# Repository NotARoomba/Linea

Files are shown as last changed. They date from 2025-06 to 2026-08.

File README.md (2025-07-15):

<h1 align="center">
  <br>
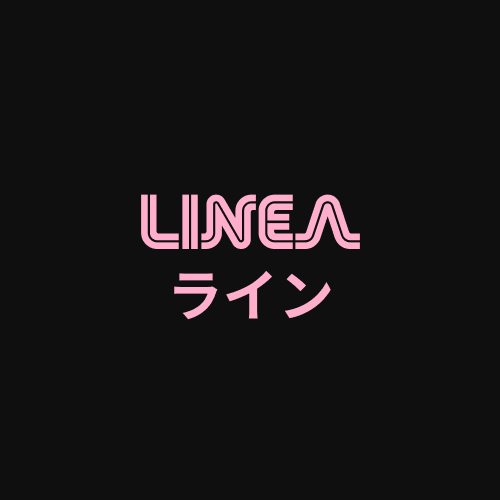
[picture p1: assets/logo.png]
Linea
  
  <br>
  Linea
  <br>
</h1>

<h4 align="center">
Project files for a custom EMR tablet from scratch.

Inspired by [Project Patchouli](https://gitlab.com/yukidama/patchouli).

</h4>

<div align="center">





</div>

<p align="center">
  <a href="#key-features">Key Features</a> •
  <a href="#case-and-cad">Case & CAD</a> •
  <a href="#pcb">PCB</a> •
  <a href="#bom">BOM</a> •
  <a href="#credits">Credits</a> •
  <a href="#license">License</a>
</p>

<!---
![schematic](https://raw.githubusercontent.com/NotARoomba/Linea/main/assets/schematic.png)
![pcb](https://raw.githubusercontent.com/NotARoomba/Linea/main/assets/pcb.png)
![build](https://raw.githubusercontent.com/NotARoomba/Linea/main/assets/windowed.png)
--->

## Key Features

- ~500kHz scanning rate
- Large (170x110mm) drawing area
- Bluetooth support (via STM32)
- USB-C for data and charging
- ~~Pen~~ (for another version)

## Case and CAD

The case includes:

- 3D printed parts: a base and a top cover
- Snap-fit case

Designed in Fusion 360.

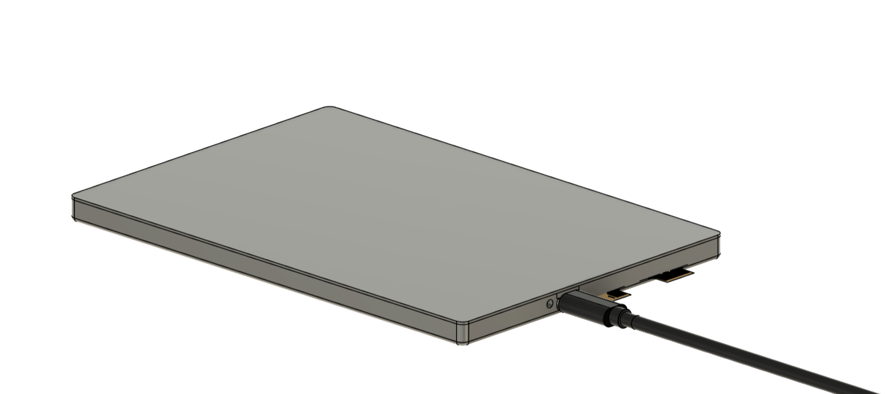
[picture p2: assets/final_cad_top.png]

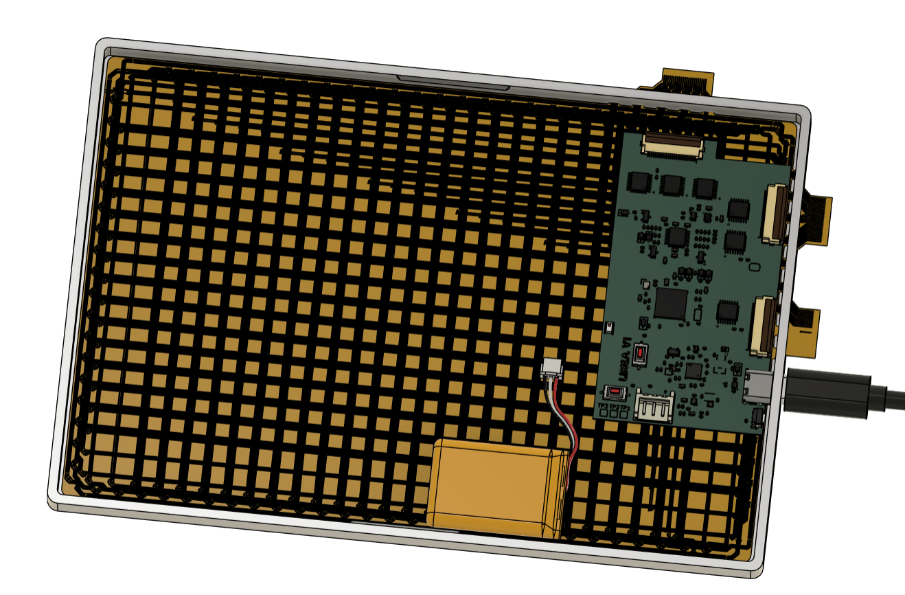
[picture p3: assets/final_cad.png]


## PCB

Designed in KiCad. Notable points:

- STM32WB55RGV6TR for bluetooth support
- LiPo battery charging circuit
- USB-C
- 2 ground planes
- FPC touchpad

The PCB has 2 components, the FPC coil grid and the main board.

### FPC

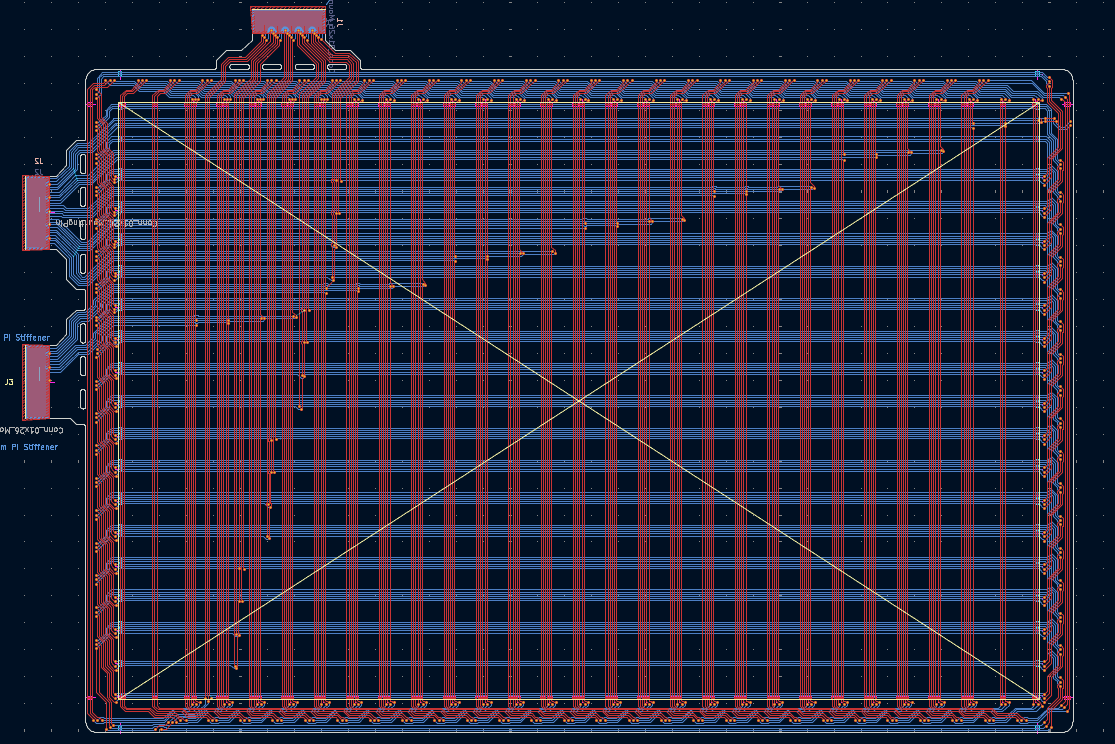
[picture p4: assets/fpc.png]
FPC board


### Main Board

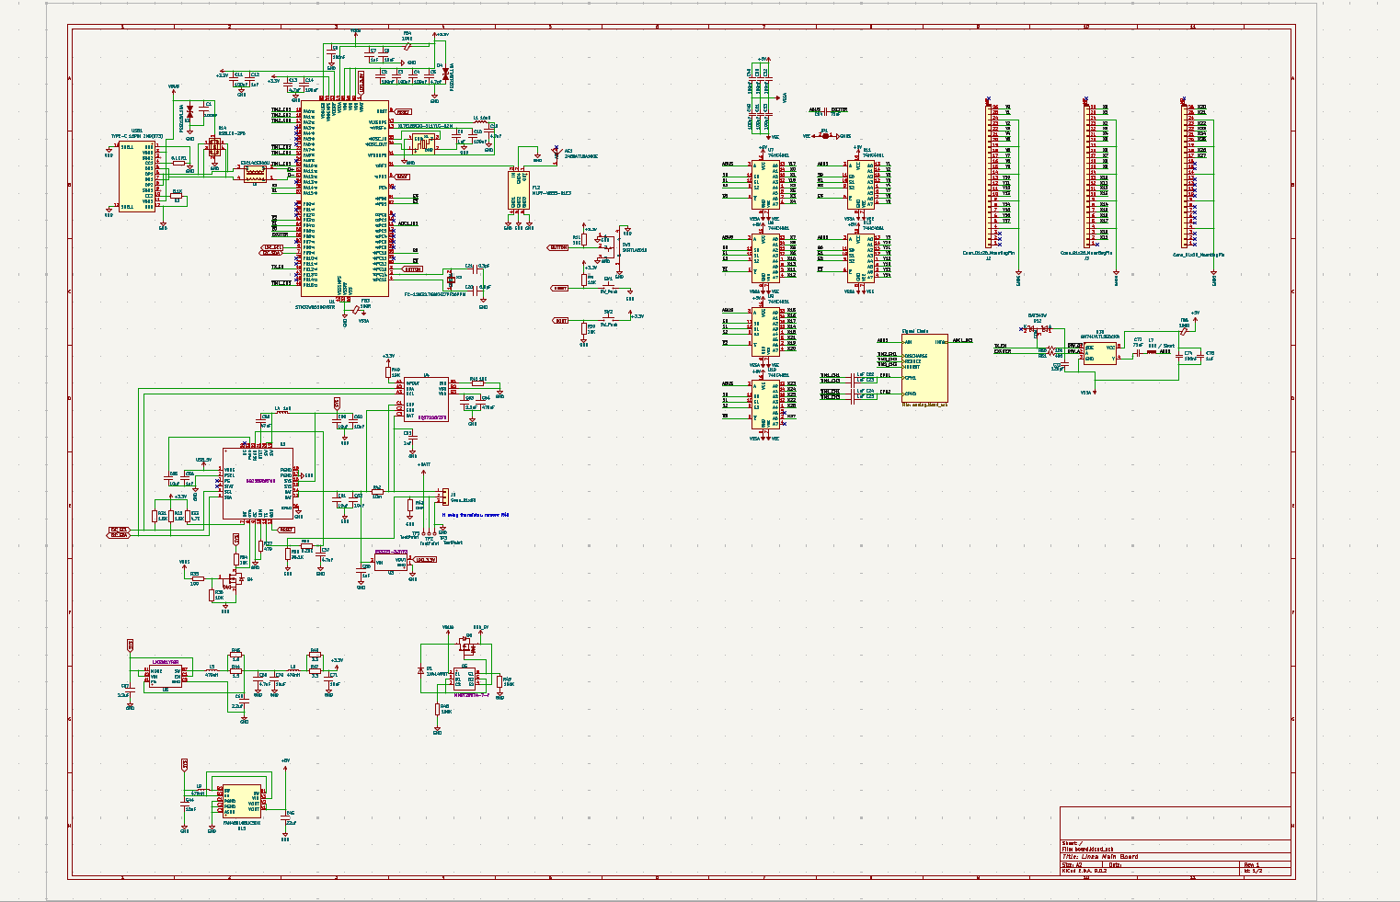
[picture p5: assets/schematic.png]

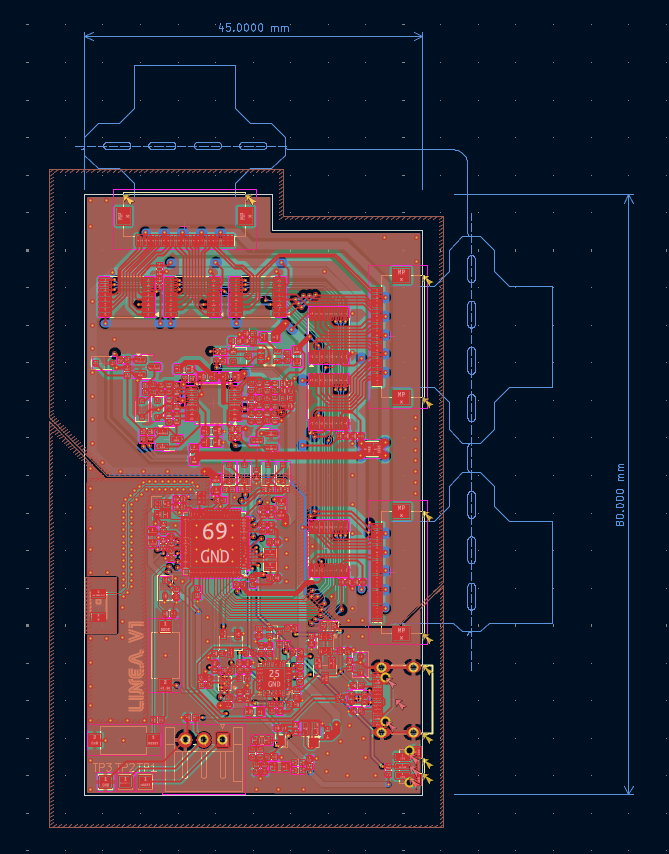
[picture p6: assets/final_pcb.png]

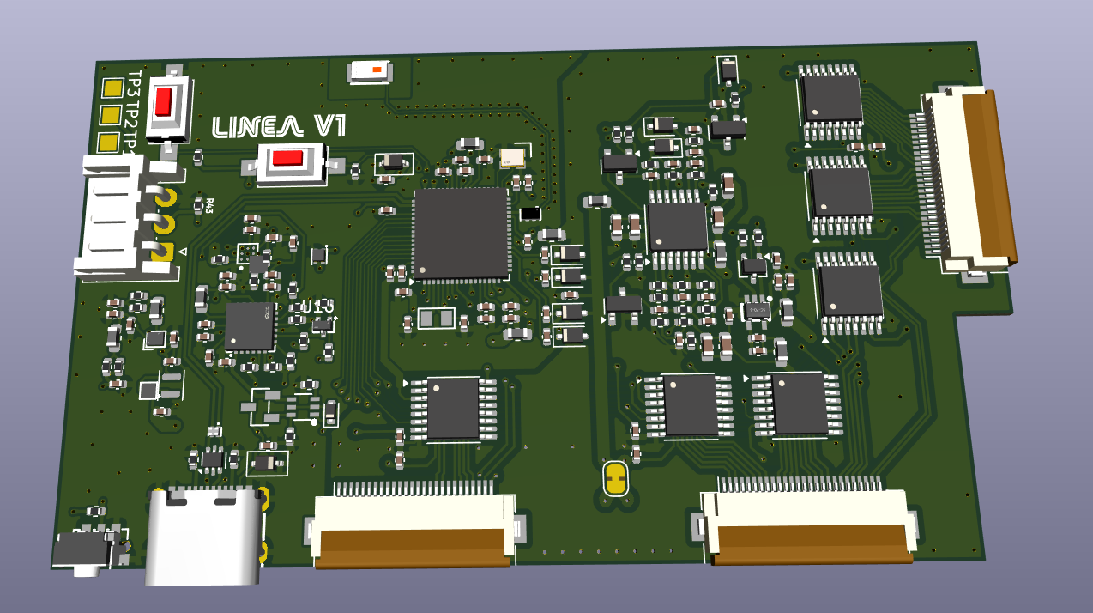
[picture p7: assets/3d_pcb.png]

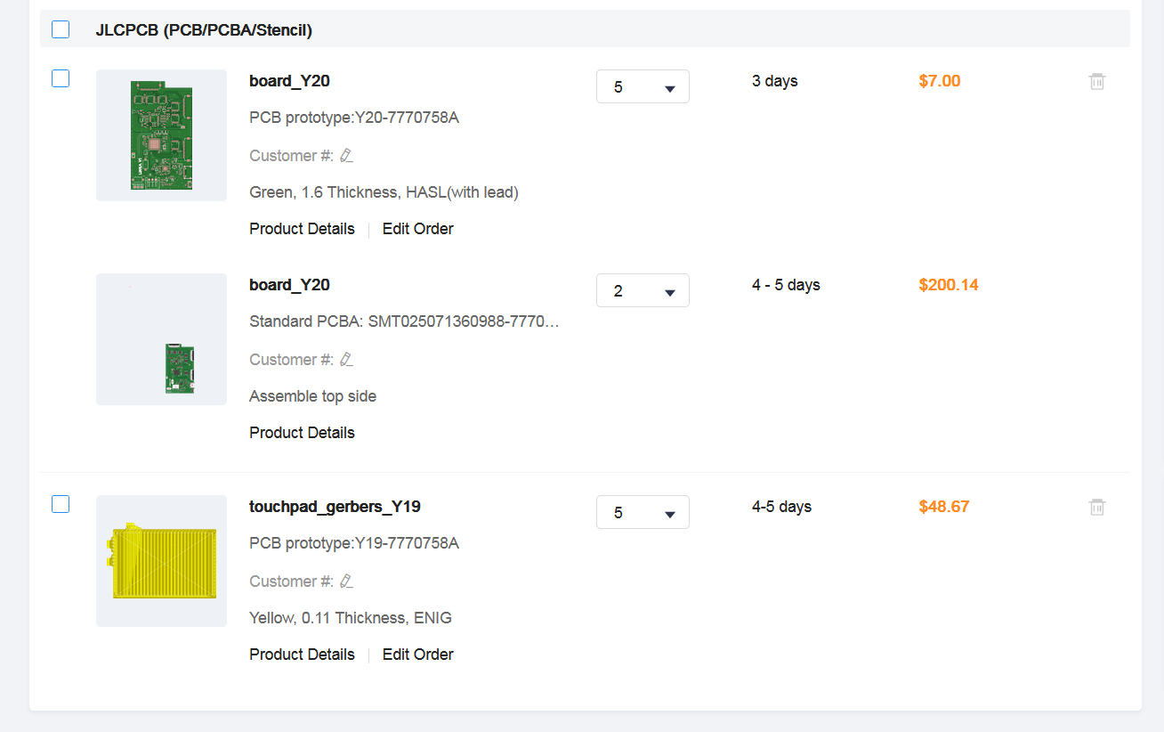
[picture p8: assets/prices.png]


## BOM

| Item | Price (USD) | Source |
| --- | --- | --- |
| FPC Board | 48.67 | JLCPCB |
| Main Board | 207.14 | JLCPCB |
| Test Pen | 12.35 | [Aliexpress](https://www.aliexpress.com/item/1005001860233195.html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) |
| LiPo 1200mAh | 12.00 | [Online Marketplace](https://articulo.mercadolibre.com.co/MCO-897219547-bateria-37v-1200mah-litio-lipo-35-x-6cm-ancho-05cm-_JM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) |
| **Subtotal** | 280.16 | |
| **Shipping** | 30.00 | Estimated |
| **Total** | 310.16 | |

<!-- https://articulo.mercadolibre.com.co/MCO-568567056-lapiz-repuesto-tabla-digitalizadora-xp-pen-p03-no-wacom-_JM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 -->

## Credits

- [Project Patchouli](https://gitlab.com/yukidama/patchouli)
- [Flipper Zero](https://docs.flipper.net/development/hardware)
- Check `/references` for more information

This project uses:

- [KiCad](https://www.kicad.org/)
- [STM32MX](https://www.st.com/en/development-tools/stm32cubemx.html)
- [Fusion 360](https://www.autodesk.com/products/fusion-360/overview)

## You may also like...

- [Niveles De Niveles](https://github.com/NotARoomba/NivelesDeNiveles) – Real-time flood alert app
- [ROCKETMEN](https://github.com/NotARoomba/ROCKETMEN) – Custom flight controller files
- [Tamaki](https://github.com/NotARoomba/Tamaki) – A cute HackPad

## License

MIT

---

> [notaroomba.dev](https://notaroomba.dev) &nbsp;&middot;&nbsp;
> GitHub [@NotARoomba](https://github.com/NotARoomba)

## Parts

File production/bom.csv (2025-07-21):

Designator | Footprint | Quantity | Value | LCSC Part #
AE1 | ANT-SMD_L3.2-W1.6 | 1 | 2450AT18A100E | C89334
C1, C10, C11, C14, C2, C3, C4, C48, C49, C50, C51, C52, C53, C6, C74 | 0402 | 15 | 100nF
C12, C22, C23, C24, C25, C56, C65, C66, C7, C75, C9 | 0402 | 11 | 1uF
C13, C15, C57, C69 | 0402 | 4 | 4.7uF
C16, C19 | 0402 | 2 | 3.9nF
C17, C27 | 0603 | 2 | 3.6nF
C18, C73 | 0402 | 2 | 68nF
C20 | 0402 | 1 | 0.8pF
C21 | 0402 | 1 | 0.3pF
C26 | 0402 | 1 | 1nF
C28, C43 | 0402 | 2 | 470pF
C29, C30, C32, C33, C35, C36, C72 | 0402 | 7 | 120pF
C31, C44, C55, C59, C60, C61, C62, C70, C71 | 0402 | 9 | 10uF
C34 | 0402 | 1 | 560pF
C37, C38 | 0603 | 2 | 1uF
C39 | 0402 | 1 | 33pF
C40, C41 | 0603 | 2 | 100nF
C42 | 0402 | 1 | 220pF
C45 | 0402 | 1 | 22uF
C5 | 0402 | 1 | 4.7pF
C58 | 0402 | 1 | 47nF
C63, C67, C68 | 0402 | 3 | 2.2uF
C64 | 0402 | 1 | 470nF
C8 | 0402 | 1 | 10nF
D1 | D_SOD-523 | 1 | 1N4148WT
D10, D11, D5, D6, D7, D8, D9 | D_SOD-323F | 7 | BAT54J
D12 | SOT-323_SC-70 | 1 | BAT54SW
D3, D4 | D_SOD-323_TVS | 2 | PESD15VL1BA
FB1, FB2, FB3, FB4, FB5 | 0603 | 5 | 100R
FL2 | FILTER-SMD_6P-L1.6-W1.0-P0.50-BL | 1 | MLPF-WB55-01E3 | C2651048
J2, J3, J4 | Hirose_FH12-26S-0.5SH_1x26-1MP_P0.50mm_Horizontal | 3 | Conn_01x26_MountingPin | C262277
J5 | JST_EH_S3B-EH_1x03_P2.50mm_Horizontal | 1 | Conn_01x03 | C263754
JP1 | SolderJumper-2_P1.3mm_Bridged_RoundedPad1.0x1.5mm | 1 | ~
L1 | 0603 | 1 | 10uH
L4 | 0603 | 1 | 1uH
L5, L6 | 0603 | 2 | 470nH
L7 | 0603 | 1 | 60R / Short | C85834
L8 | FILTER-SMD_4P-L0.9-W0.7-P0.50-BL | 1 | EXC14CE900U | C178761
L9 | L_Murata_DFE201610P | 1 | 470nH | C882980
Q1, Q2, Q3 | SOT-23 | 3 | AO3400A
Q4 | SOT-523-3_L1.6-W0.8-P1.00-LS1.6-BR | 1 | ~ | C155524
Q5 | SOT-363_L2.0-W1.3-P0.65-LS2.1-BL | 1 | ~ | C460232
Q6 | SOT-23-3_L2.9-W1.3-P1.90-LS2.4-BR | 1 | ~ | C177033
R1, R2 | 0402 | 2 | 5.1K
R10, R11, R15, R21, R25, R29, R34, R36, R40, R41, R50, R9 | 0402 | 12 | 10K
R12, R14, R16, R23 | 0402 | 4 | 1K
R13, R51 | 0402 | 2 | 400
R17, R19, R22, R26 | 0402 | 4 | 12K
R18 | 0402 | 1 | 0
R20 | 0402 | 1 | 560
R24 | 0402 | 1 | 200
R27, R30, R35 | 0402 | 3 | 100
R28 | 0402 | 1 | 15k
R31, R32 | 0402 | 2 | 1.5K
R33 | 0402 | 1 | 4.7K
R37 | 0402 | 1 | 470
R38 | 0402 | 1 | 30.1K
R39 | 0402 | 1 | 5.23K
R42 | R2512 | 1 | WW25WR010FTL | C171418
R43 | 0402 | 1 | DNP
R44, R45 | 0402 | 2 | 1.5
R46, R47 | 0402 | 2 | 3.3
R48, R49 | 0402 | 2 | 100K
SW1, SW2 | SW_SPST_CK_RS282G05A3 | 2 | SW_Push | C318938
SW3 | KEY-SMD_SKRTLAE010 | 1 | SKRTLAE010 | C110293
TP1, TP2, TP3 | TestPoint_Pad_1.5x1.5mm | 3 | TestPoint
U1 | QFN-68-1EP_8x8mm_P0.4mm_EP6.4x6.4mm | 1 | STM32WB55RGV6
U10, U11, U12, U7, U8, U9 | TSSOP-16_4.4x5mm_P0.65mm | 6 | 74HC4051
U13 | SC-70-5_L2.1-W1.3-P0.65-LS2.1-TL | 1 | SN74LV1T125DCKR | C75925
U14 | SOT-666 | 1 | USBLC6-2P6
U15 | WLCSP-9_L1.2-W1.2-R3-C3-P0.40-BL | 1 | FAN48610BUC50X | C890711
U16 | UTDFN-4_L1.0-W1.0-P0.63-BL-EP-1 | 1 | RS3221-3.3YUTDN4 | C2924279
U2 | QFN-24_L4.0-W4.0-P0.50-TL-EP2.7 | 1 | ~ | C181475
U4 | DSBGA-9_L1.7-W1.6-R3-C3-P0.50-BL | 1 | ~ | C528617
U5 | DSBGA-6_L1.4-W1.1-R3-C2-P0.40-BL | 1 | ~ | C2070970
U6 | TSSOP-14_4.4x5mm_P0.65mm | 1 | COS8054TR
USB1 | USB-C-SMD_TYPE-C-6PIN-2MD-073 | 1 | TYPE-C 16PIN 2MD(073) | C2765186
X1 | CRYSTAL-SMD_4P-L2.0-W1.6-BL | 1 | XL7EL89CKI-111YLC-32M | C2965582
X2 | FC-12M_L2.0-W1.2 | 1 | FC-12M32.768KHZ7PF20PPM | C99009

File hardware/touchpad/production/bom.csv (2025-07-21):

Designator | Footprint | Quantity | Value | LCSC Part #
J1, J2, J3 | Hirose_FH12-26S-0.5SH(55)-FPC_1 | 3 | Conn_01x26_MountingPin
J10, J100, J101, J102, J103, J104, J105, J106, J107, J108, J109, J11, J110, J111, J112, J113, J114, J115, J116, J117, J118, J119, J12, J120, J121, J122, J123, J124, J125, J126, J127, J128, J129, J13, J130, J131, J132, J133, J134, J135, J136, J137, J138, J139, J14, J140, J141, J142, J143, J144, J145, J146, J147, J148, J149, J15, J150, J151, J152, J153, J154, J155, J156, J157, J158, J159, J16, J160, J161, J162, J163, J164, J165, J166, J167, J168, J169, J17, J170, J171, J172, J173, J174, J175, J176, J177, J178, J179, J18, J180, J181, J182, J183, J184, J185, J186, J187, J19, J20, J21, J22, J23, J24, J25, J26, J27, J28, J29, J30, J31, J32, J33, J34, J35, J36, J37, J38, J39, J4, J40, J41, J42, J43, J44, J45, J46, J47, J48, J49, J5, J50, J51, J52, J53, J54, J55, J56, J57, J58, J59, J6, J60, J61, J62, J63, J64, J65, J66, J67, J68, J69, J7, J70, J71, J72, J73, J74, J75, J76, J77, J78, J79, J8, J80, J81, J82, J83, J84, J85, J86, J87, J88, J89, J9, J90, J91, J92, J93, J94, J95, J96, J97, J98, J99 | coil_terminal_3p | 184 | Conn_02x03_Odd_Even

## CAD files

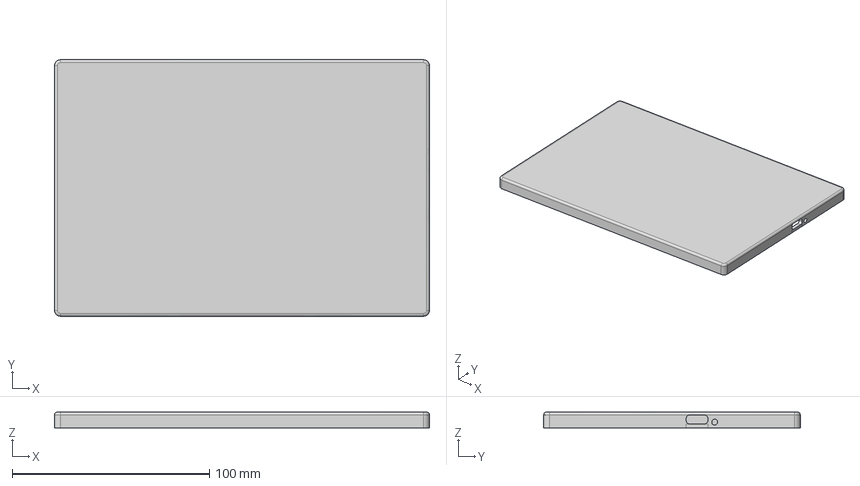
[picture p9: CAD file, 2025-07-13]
production/case_base.step
190.0 x 130.0 x 8.00 mm

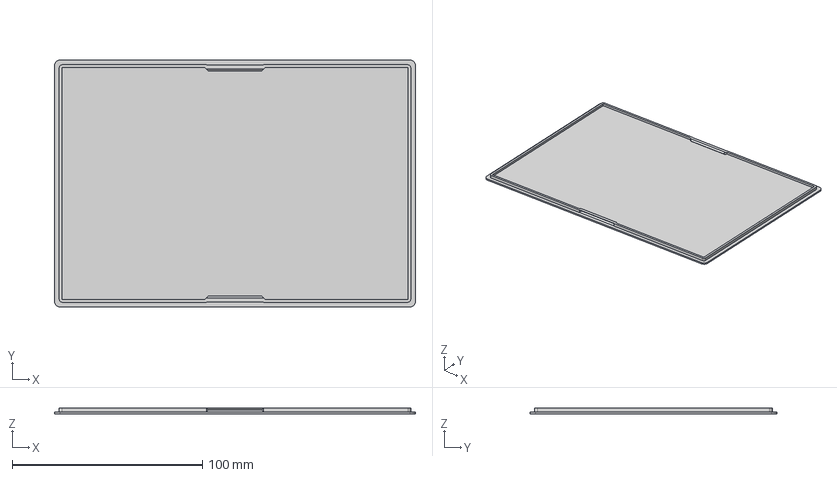
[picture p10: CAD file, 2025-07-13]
production/case_top.step
190.0 x 130.0 x 3.00 mm

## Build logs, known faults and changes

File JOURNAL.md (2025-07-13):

---
title: "Linea"
author: "Nathan Alspaugh (NotARoomba)"
description: "An EMR based drawing tablet (like a Wacom) from scratch!"
created_at: "2025-06-20"
time_spent: ~64 Hours
---

# July 20-22: Brainstorming and Research

I was initially inspired to start this project after the principal of my school promised me a Wacom One because of my academic excellence, but after some time I never recieved the tablet so I decided to make my own. I then looked up to see if I could find some inspiration and I found a [YouTube video](https://www.youtube.com/watch?v=igVscvWAR1s) (<10K views) of someone actually making and studying the pencils from common drawing tablets.

EMR tablets work based off of inductors (coils) being able to b affected by magnetic fields and being able to turn such fields into electricity (with some caveats). The tablet has a grid of coils ith AC current flowing through them, this alternation causes a magnetic field to form. THis magnetic field is especially useful because if another inductor coms close to the field, it can recive a bit of current and using a capacitor, it can be stored. This is the basic principle of how those pens manage to work without batteries.

I saw that he originally made on to convert a laptop into a drawing tablet so I kinda wanted to do the same but with some improvements:

- USB-C
- Bluetooth
- Custom software to configure pen sensitivity

As the original tablet neded a wired connection I decided that this would be a fun challenge to tackle.

After looking through the repository on GitLab and opeing up the schematics for the tablet (more specifically the coil grid) I was greeted with this:

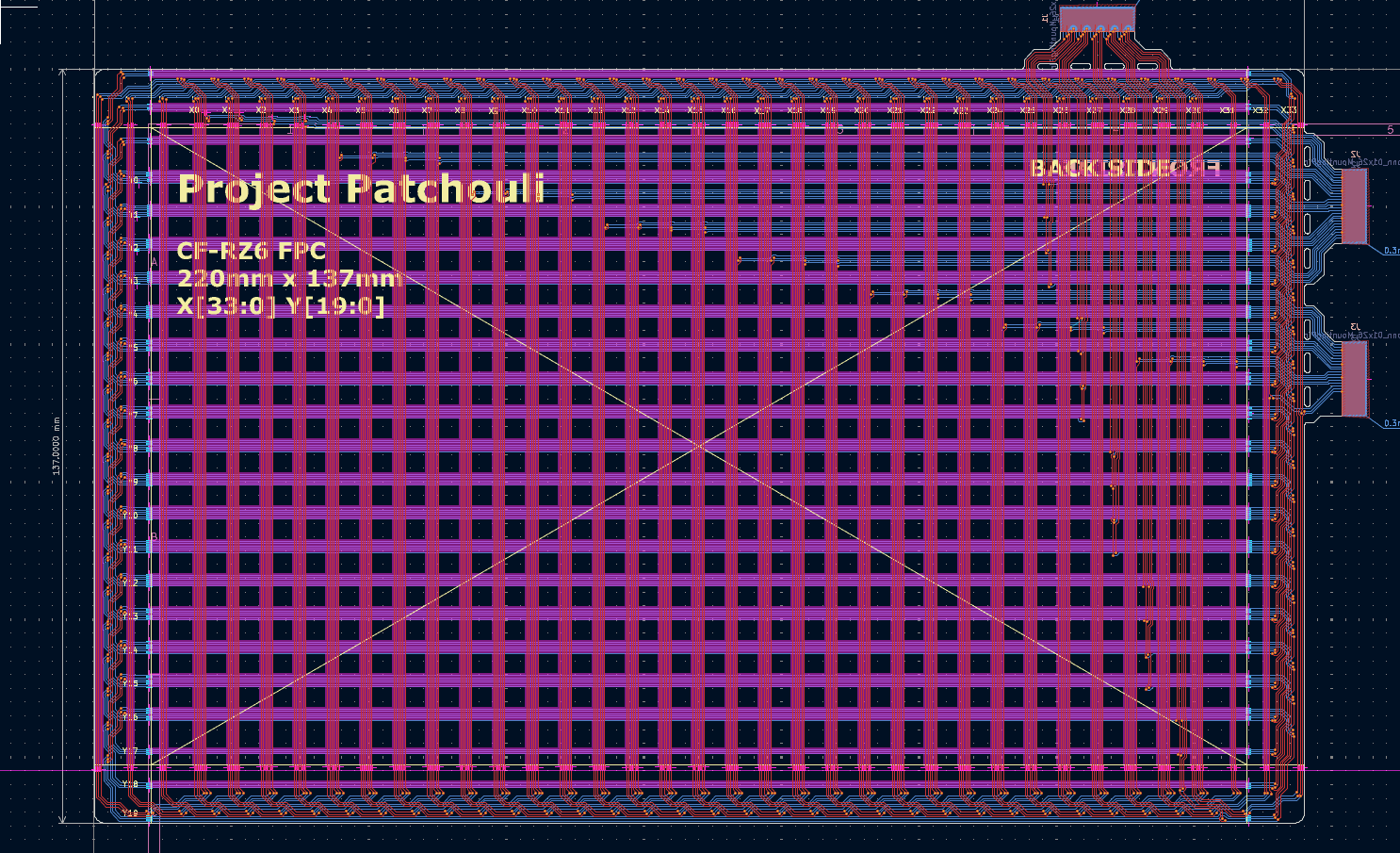
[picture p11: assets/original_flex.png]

(look at all those coils)

While I could copy it, I wanted a tablet under 200mm and also to be able to understand it. So I looked through some [patents](https://patents.google.com/patent/US4634973A) that were referenced in the YouTube video and found that that the coils could be made up of any number of turns, in this case 3 turns (better pen detection).

I plan on making 3 components, a flexible circuit that recives the signal from the pen, a central "motherboard" that processes the signal from the FPC, and finally a ~~pen that can interact with the tablet~~ (seperate project).

**Time Spent:** 2 Hours

# June 23: FPC Design

I started by using a script to make one side of the coils.

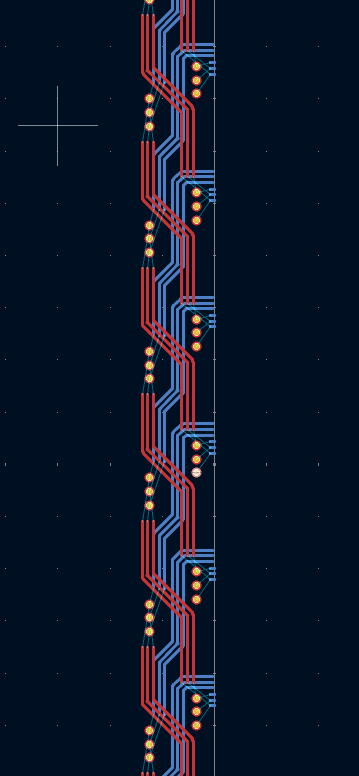
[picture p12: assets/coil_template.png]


I then had to connect them in a way so that they looped around like in the original schematic

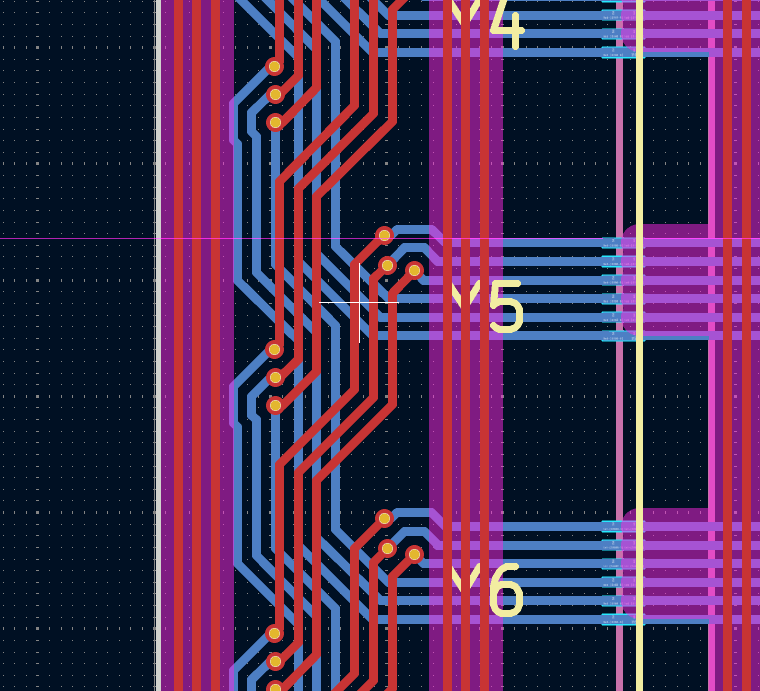
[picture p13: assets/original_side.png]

(orignal)

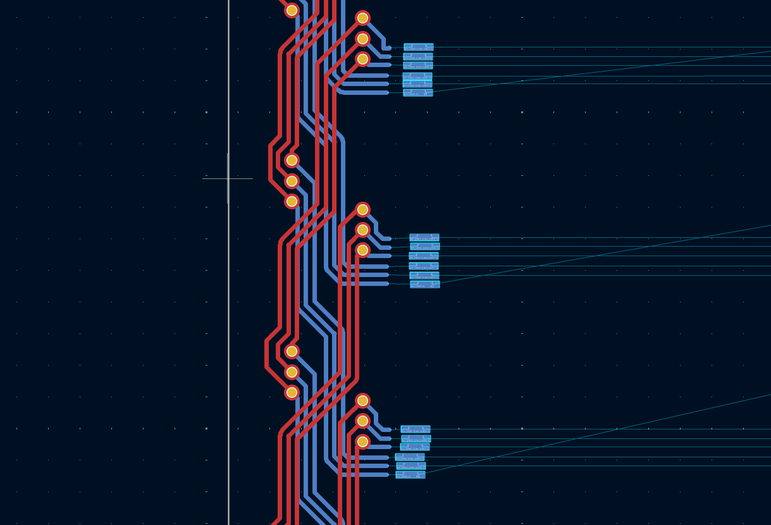
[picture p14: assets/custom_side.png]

(mine after complting the horizontal coils)

**Time Spent:** 5 Hours

# June 24: FPC continued...

After a while I got the Y-plane done

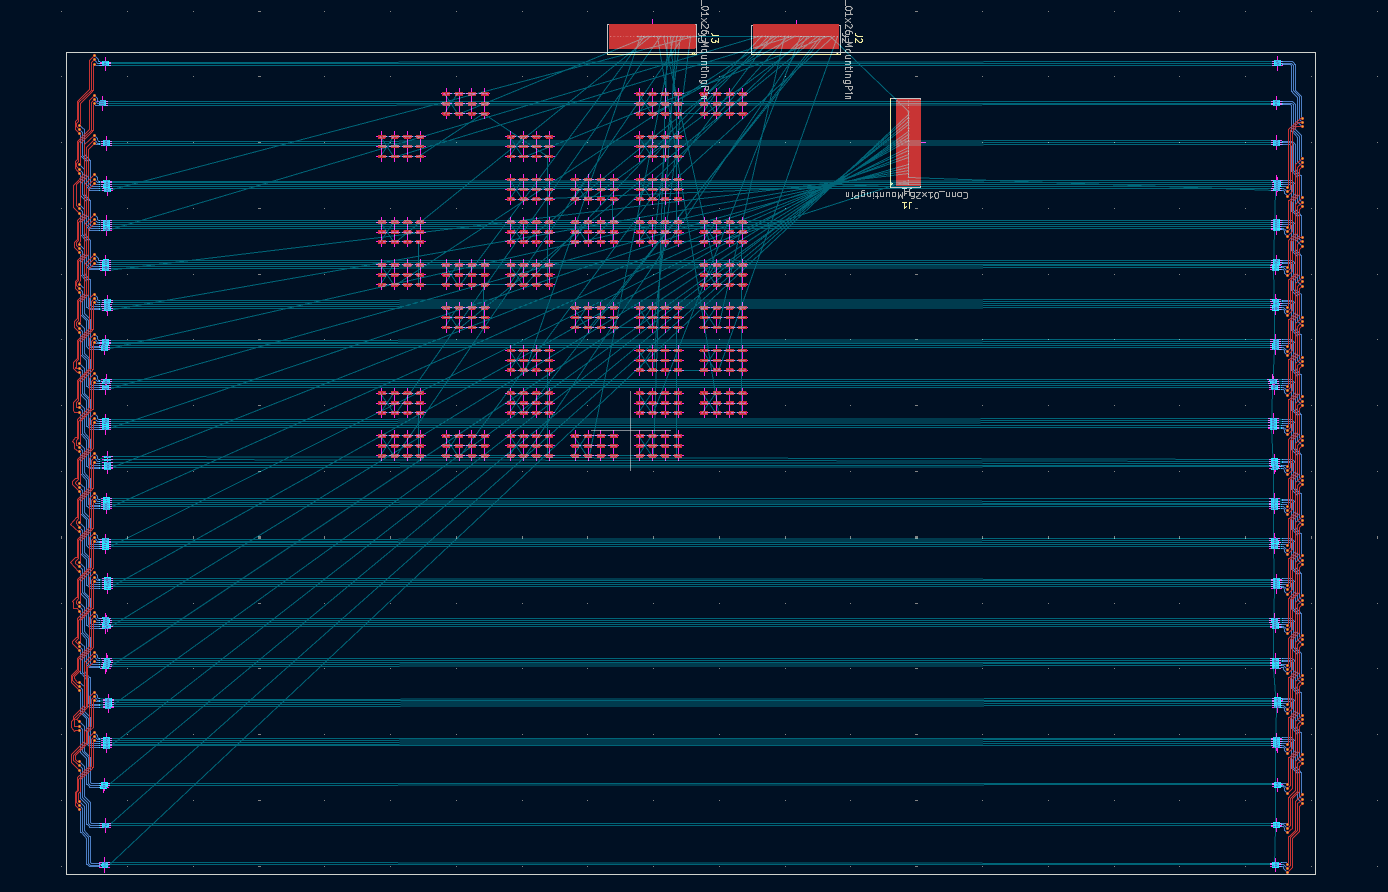
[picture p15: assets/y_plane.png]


but thats when I recieved a response from the original creator about a question I had about the coil design. Originally the coils looked like this, and I had a question as to why the middle loop wasn't connected to anything. Apparently that was a bug... after all that wiring...

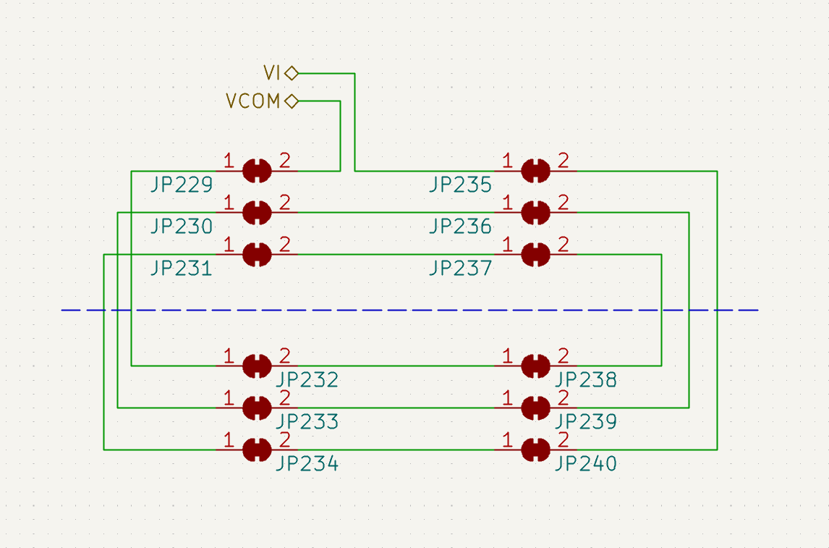
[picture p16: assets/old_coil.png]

(old coil)

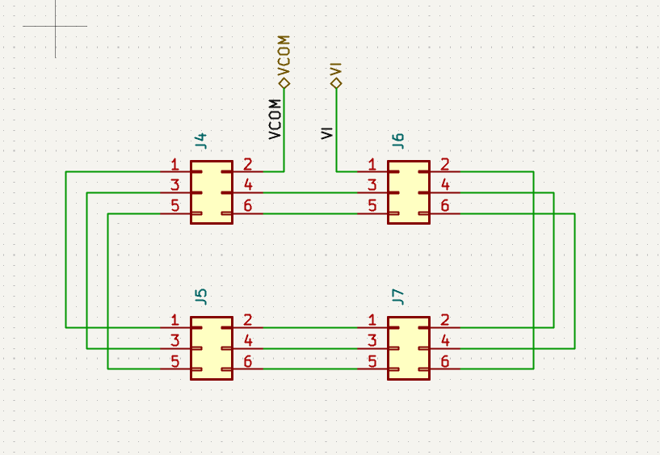
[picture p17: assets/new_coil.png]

(new coil)

I asked few more questions that helped clarify things like the trace width and how to efficently connect all the components and got to work on a new design. (by hand)

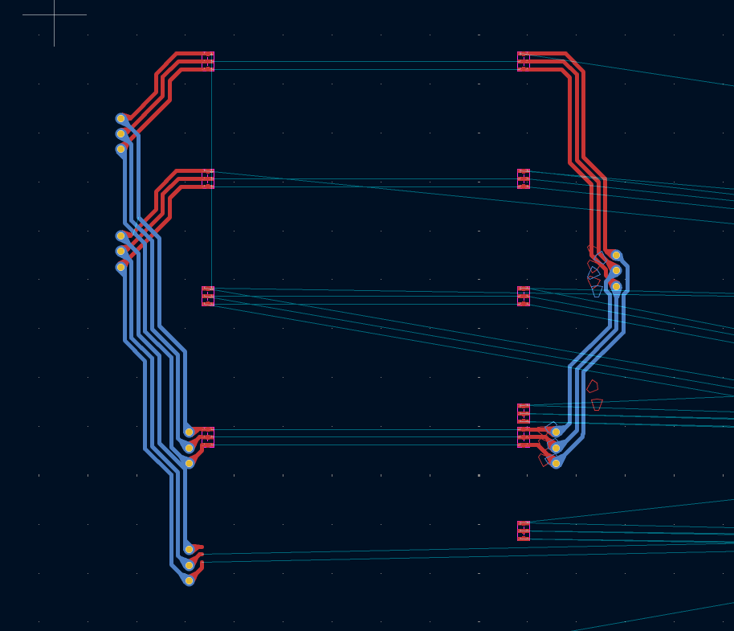
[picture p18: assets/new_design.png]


After a few hours of tweaking I finally got the right design.
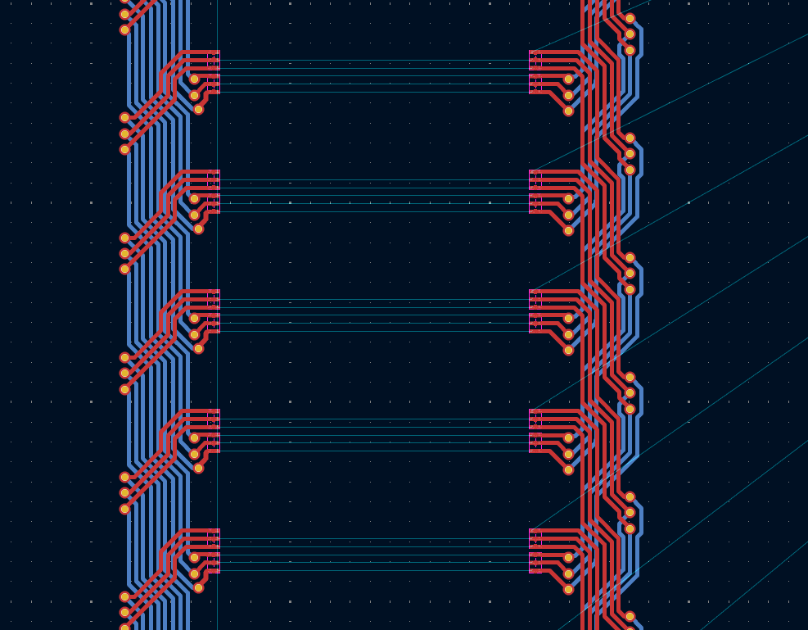
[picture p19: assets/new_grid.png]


**Time Spent:** 7 Hours

# June 25: Rewiring (again...)

After yesterday's fail I decided to take a break and then start the wiring again, I didn't make much progress today but I got both axis done.

**Time Spent:** 1 Hour

# June 29: Finished FPC

FInally after working all day (took a few days off), I finally completed the FPC.



The supposed active area is 170x110mm which I think is pretty good.

Now I'm going to start research on the main board that connects to the FPC. I want it to have bluetooth and a good battery life so I chose the STM32WB55. I'll be using the Flipper Zero's schematics to wire it up as it uses the same chip.

**Time Spent:** 8 Hours

# June 30: Main Board Schematic

After researching and compiling schematics, I started work on creating the schematic for the board that will handle the connection from the touchpad and also bluetooth. I took inspiration from the connections for power and battery from the Flipper Zero docs and also the analog circuits from [Patchouli's repository](https://gitlab.com/yukidama/patchouli).



**Time Spent:** 6 Hours

# July 1: Main Board PCB

After finishing the schematic, I decided to take a break and plan what I had to do next in order of importance.

- Double triple check schematic
- Create main board PCB
- Fix FPC board to have 0.2mm trace spacing
- Create case in Fusion360
- (Optionally create pencil)

# July 3: Fix FPC Board

My OCD wouldn't let me move on until I'd fixed spacing on the board so I redid the coils and added everything again.

**Time Spent:** 4 Hours

# July 5-10: Main Board PCB (finally)

I started work on making the PCB and after watching a few tutorials on analog signals and pcb design (thanks Phil's Lab) I felt confident in starting to design the PCB.

I started by grouping all the components together based on the schematic and also taking refrence from the other designs in Patchouli (dont have many pictures as I was locked in). I then started wiring again taking inspiration from the schmatics using wider traces for power and ground and thn smaller traces for the data lines and analog crcuits. I also split the schematic into 2 ground planes. One for analog ground and another for the digital ground.

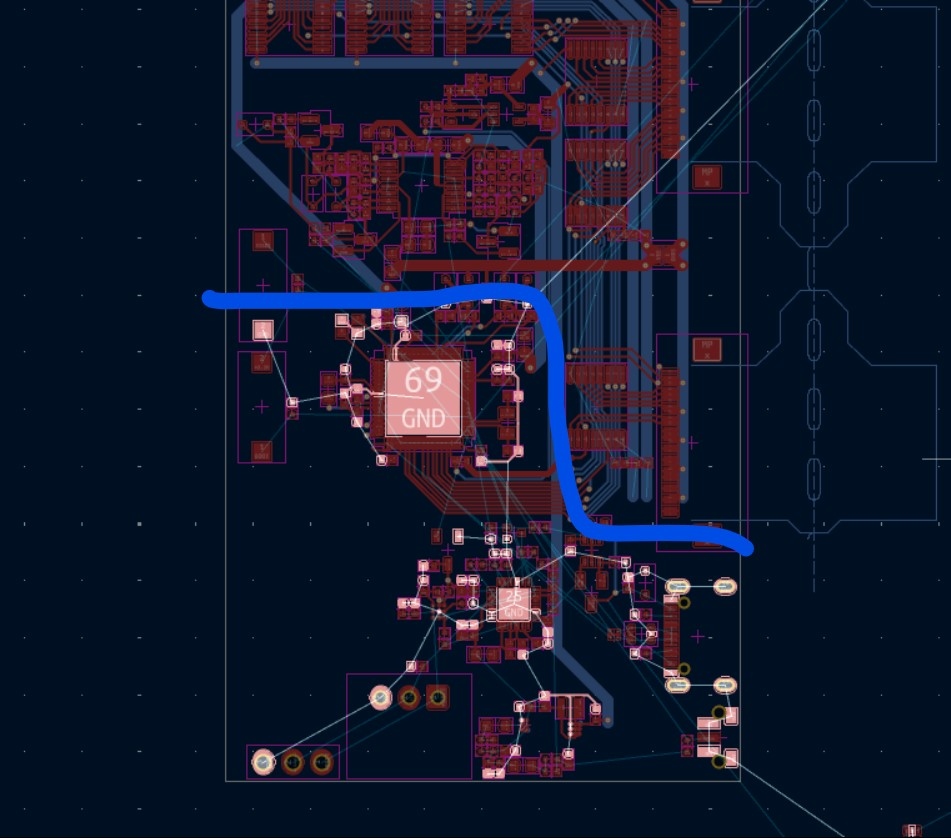
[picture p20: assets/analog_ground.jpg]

(was already done placing the components)

After wiring a bit I finished the design (almost) but I had forgot on important part, the Blutooth chip.

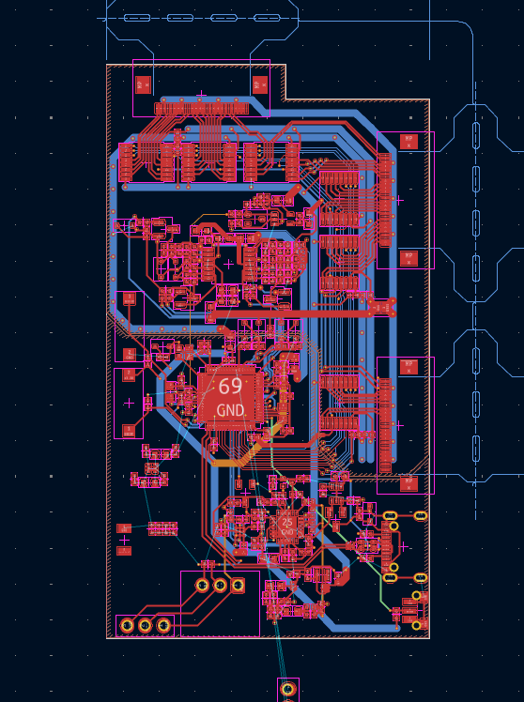
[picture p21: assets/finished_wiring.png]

(finished wireup)

It was gonna be tricky because the rf pin is on the top of the chip.

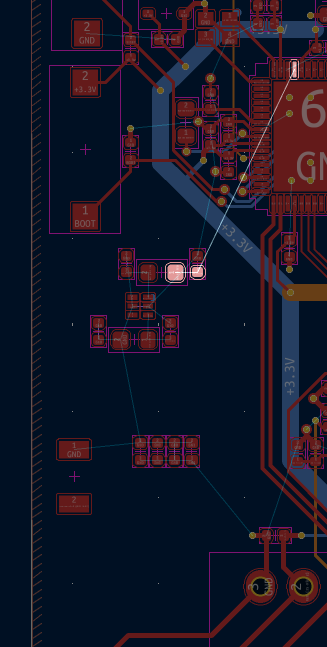
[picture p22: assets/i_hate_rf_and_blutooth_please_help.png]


but I have a 4-layer stackup so I worked on allowing a clear path for the RF trail...

**Time Spent:** 22 Hours

# July 11-12: Bluetooth Trail

After watching a few tutorials and looking at the datasheets for the STM32, I added the recommended low pass filter (also from STM).

I looked through the datasheets for the chip and found that I needed to ground EVERYTHING. So I then cleared up the buttons and moved them out of the way to create this monstrocity.

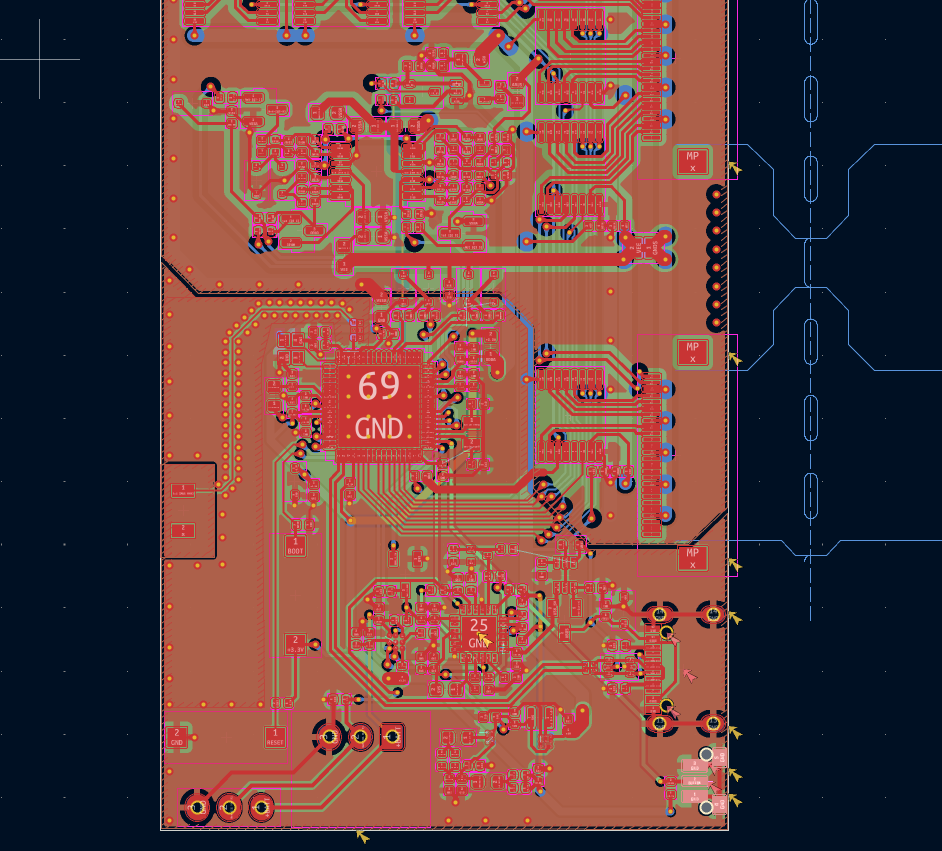
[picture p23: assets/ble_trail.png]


Aftre complting that, I fixd som DRC errors and finished the board!

**Time Spent:** 4 Hours

# July 12: CAD Design

I wanted a simple 3D printed case so I opened up Fusion360 and started work.

After a bit of designing I ended up with this.

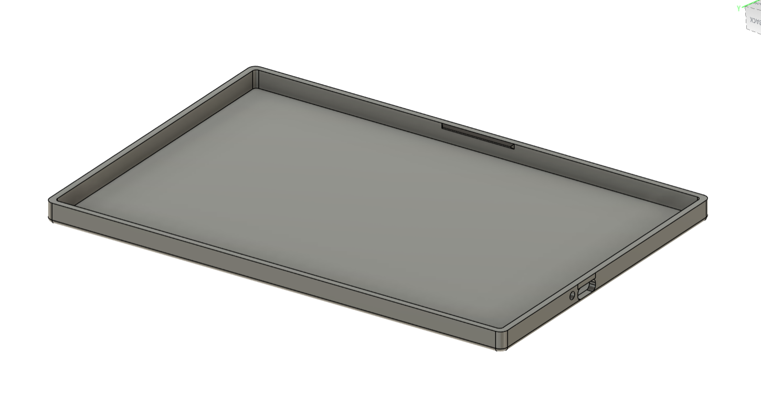
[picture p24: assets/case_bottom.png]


I added a 'hook" so that the lid can snap onto the case.

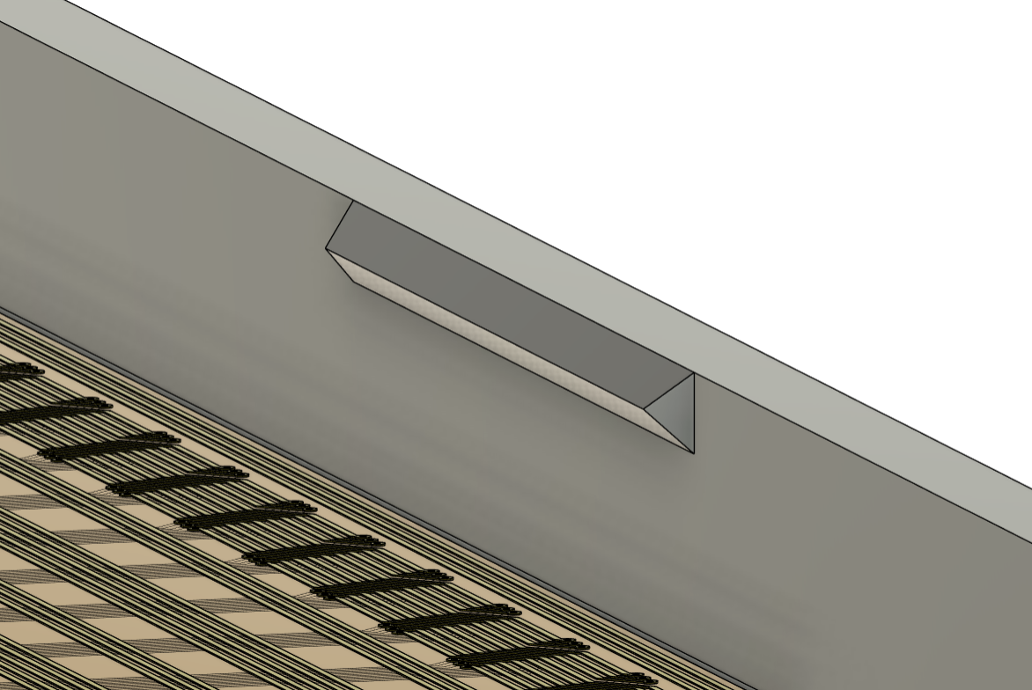
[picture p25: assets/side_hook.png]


But then after adding the components I as left with the top FPC connector a bit misaligned...

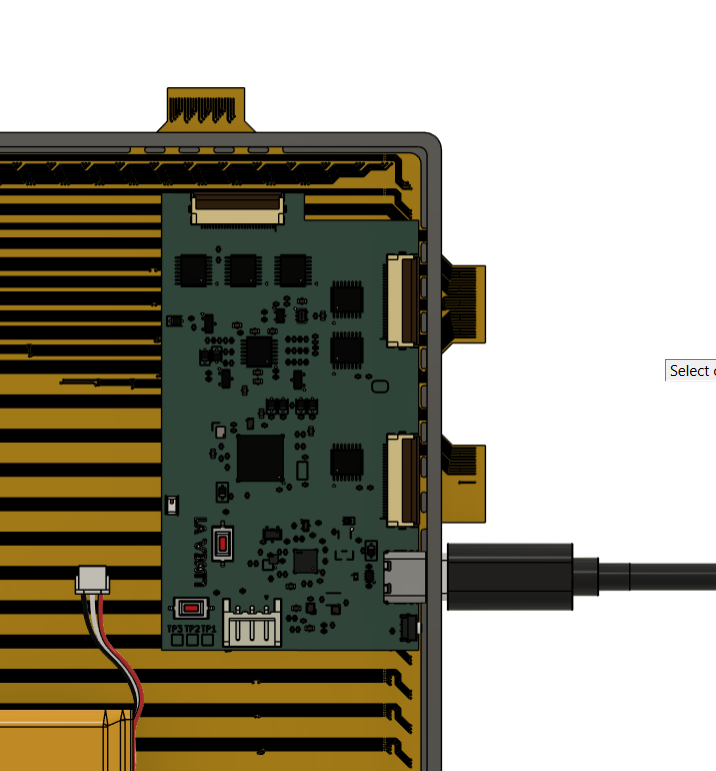
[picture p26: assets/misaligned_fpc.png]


So I went back to KiCad and rewired it.

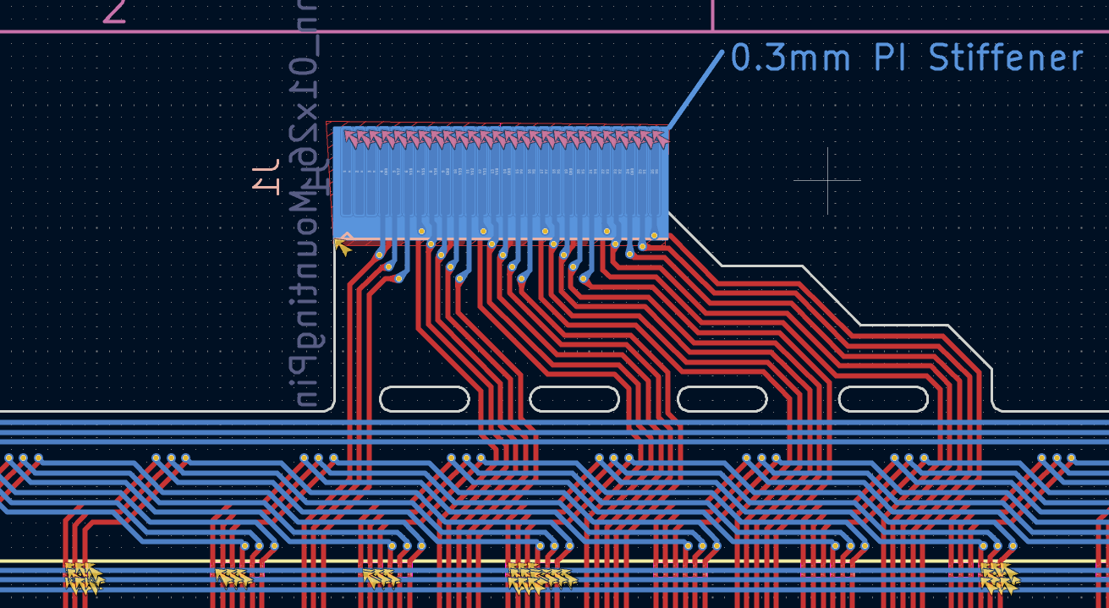
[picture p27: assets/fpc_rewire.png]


After adding the other battery and testing the USB-C port, I finished the case design





**Time Spent:** 5 Hours

# July 13: JLCPCB Quote

I added all the designators and LCSC part numbers to the properties of each part and got a subtotal of ~207$ for the main board and ~48$ for the FPC



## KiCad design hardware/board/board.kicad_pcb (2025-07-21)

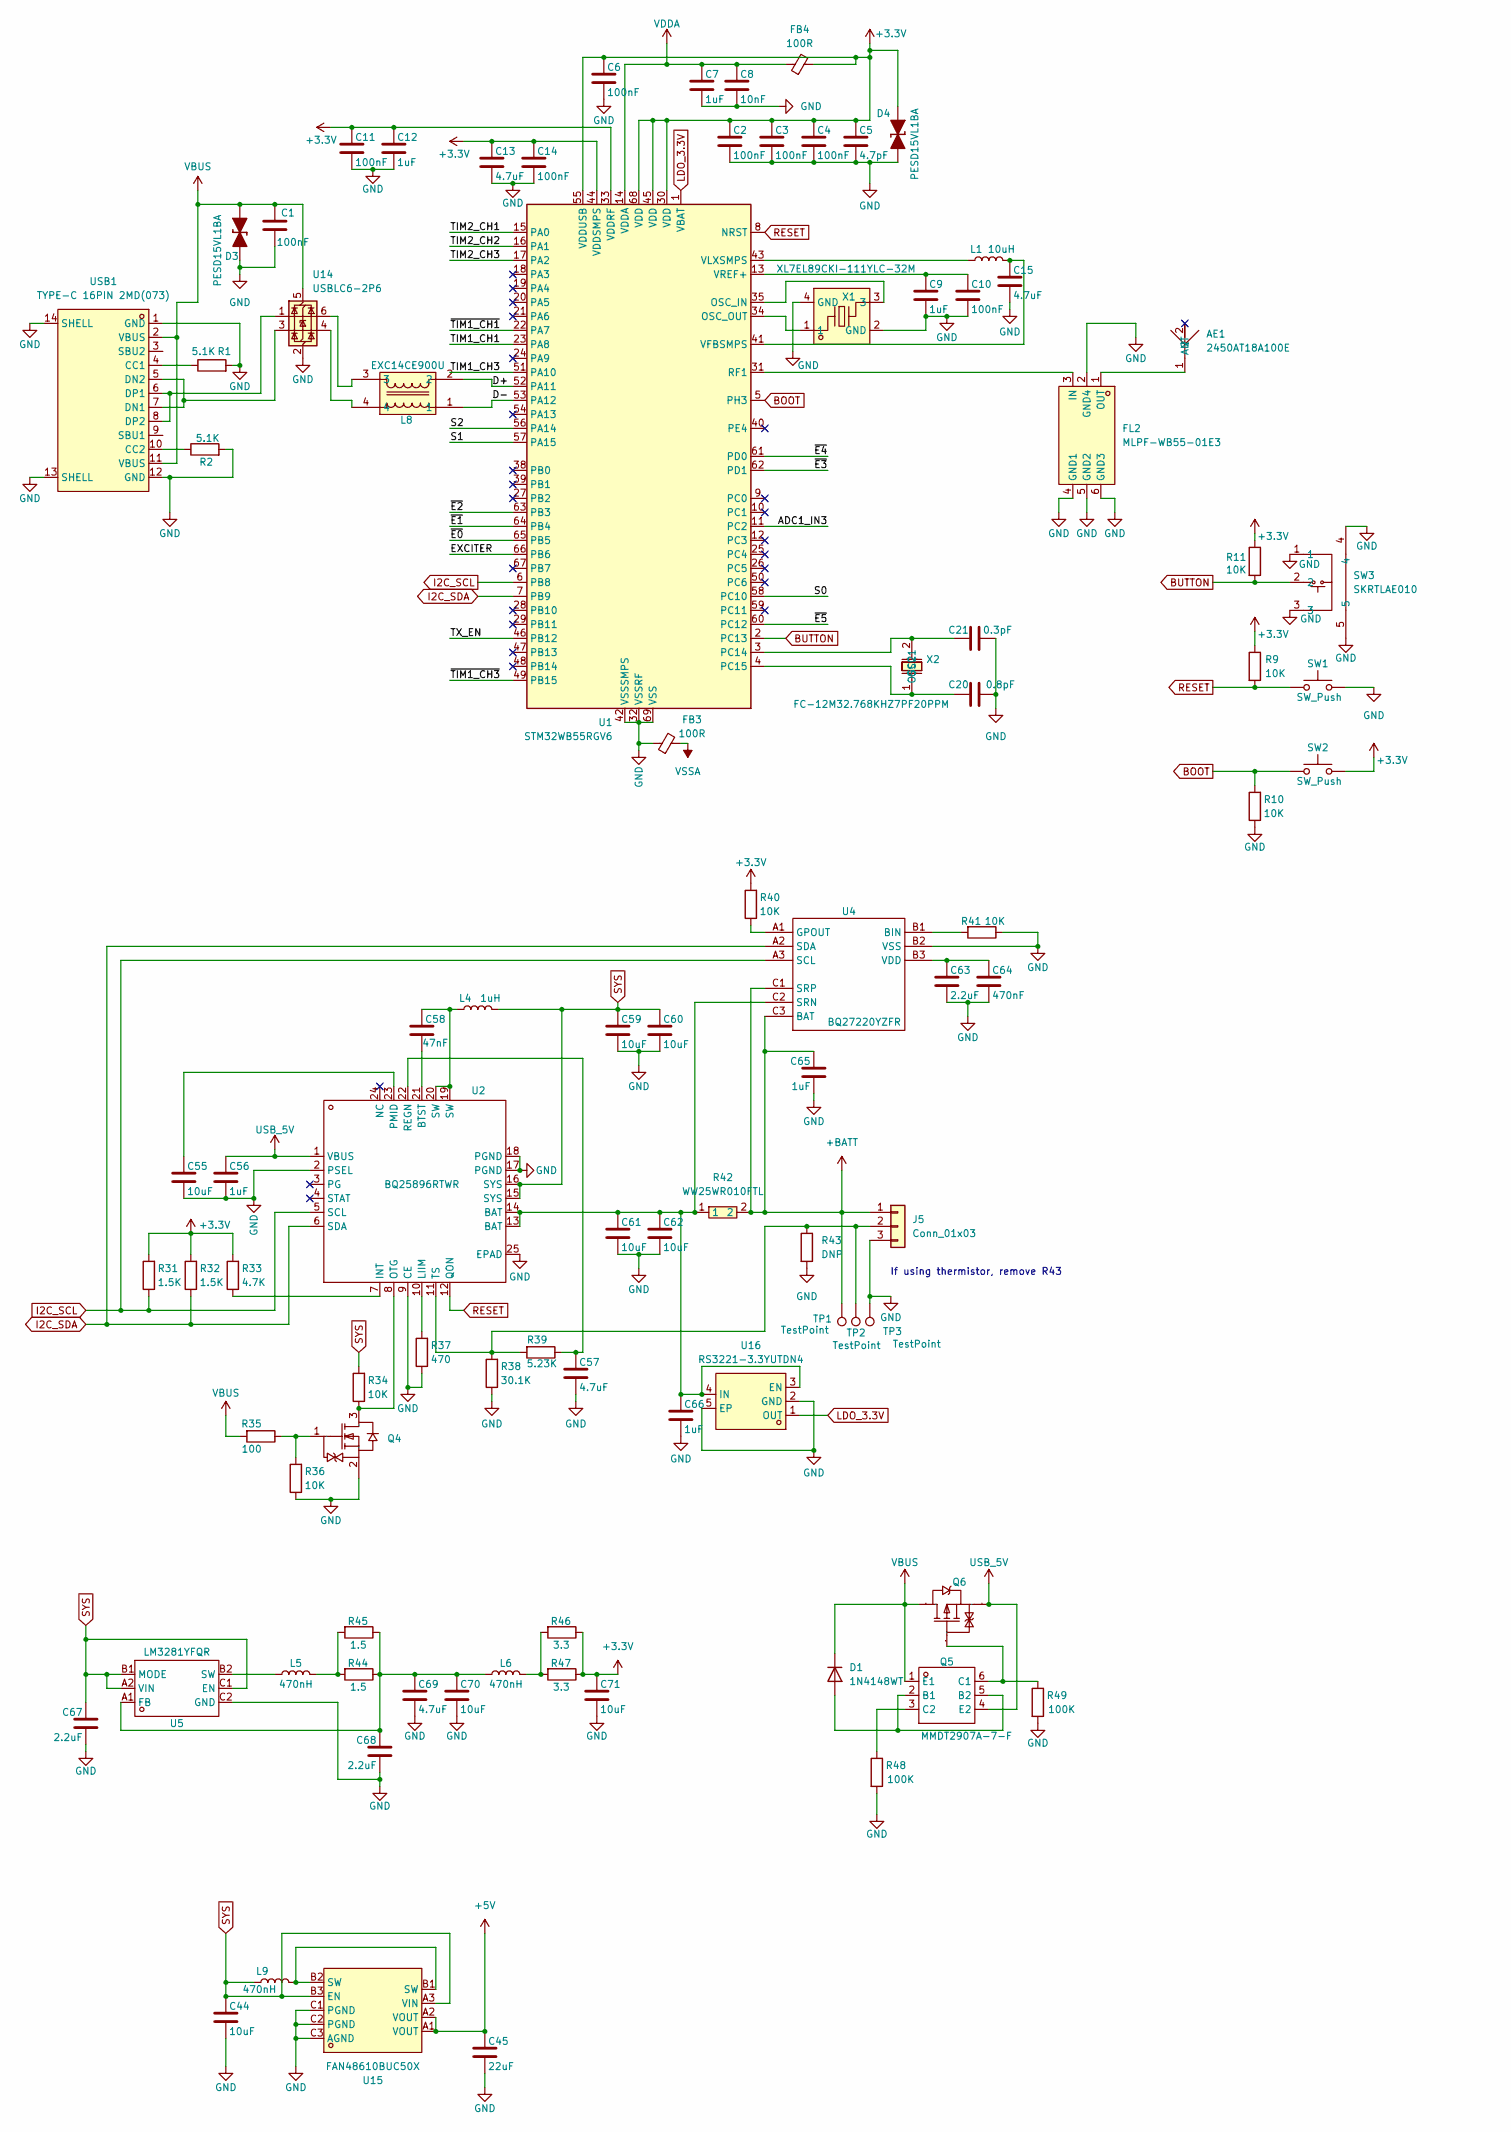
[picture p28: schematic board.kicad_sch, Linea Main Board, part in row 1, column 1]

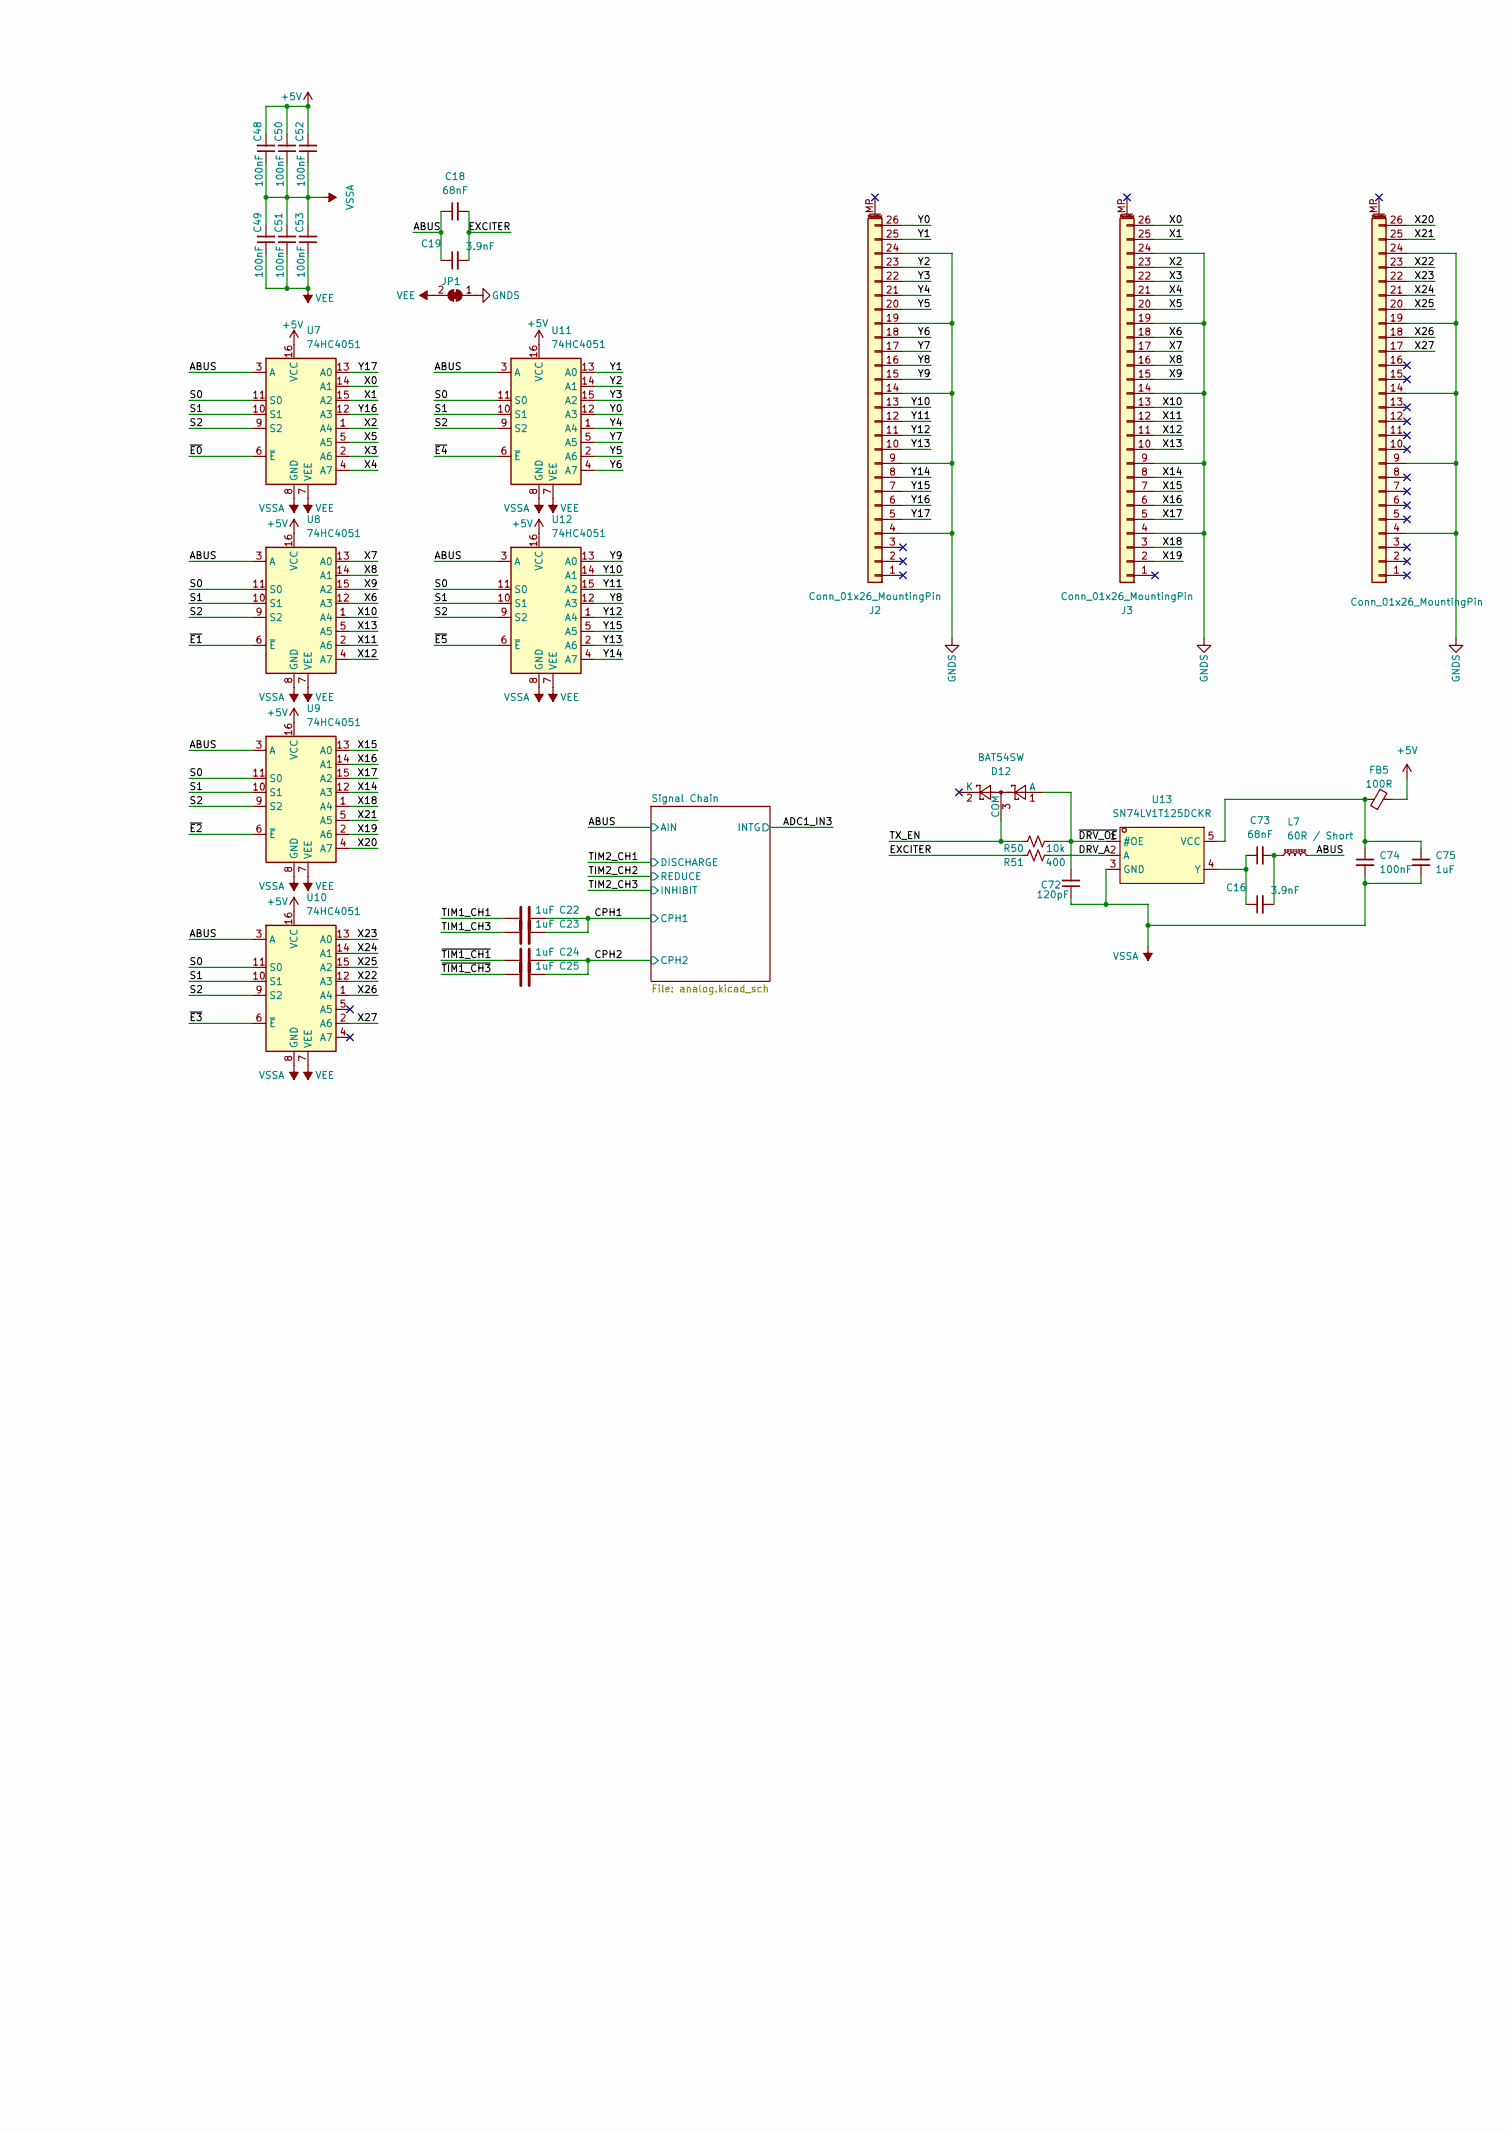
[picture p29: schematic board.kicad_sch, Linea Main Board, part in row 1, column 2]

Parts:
AE1: 2450AT18A100E; ANT-SMD_L3.2-W1.6; LCSC Part C89334
C1, C2, C3, C4, C6, C10, C11, C14, C48, C49, C50, C51, C52, C53, C74: 100nF; C_0402_1005Metric
C5: 4.7pF; C_0402_1005Metric
C7, C9, C12, C22, C23, C24, C25, C56, C65, C66, C75: 1uF; C_0402_1005Metric
C8: 10nF; C_0402_1005Metric
C13, C15, C57, C69: 4.7uF; C_0402_1005Metric
C16, C19: 3.9nF; C_0402_1005Metric
C18, C73: 68nF; C_0402_1005Metric
C20: 0.8pF; C_0402_1005Metric
C21: 0.3pF; C_0402_1005Metric
C44, C55, C59, C60, C61, C62, C70, C71: 10uF; C_0402_1005Metric
C45: 22uF; C_0402_1005Metric
C58: 47nF; C_0402_1005Metric
C63, C67, C68: 2.2uF; C_0402_1005Metric
C64: 470nF; C_0402_1005Metric
C72: 120pF; C_0402_1005Metric
D1: 1N4148WT; D_SOD-523
D3, D4: PESD15VL1BA; D_SOD-323_TVS
D12: BAT54SW; SOT-323_SC-70
FB3, FB4, FB5: 100R; L_0603_1608Metric
FL2: MLPF-WB55-01E3; FILTER-SMD_6P-L1.6-W1.0-P0.50-BL; LCSC Part C2651048
J2, J3, J4: Conn_01x26_MountingPin; Hirose_FH12-26S-0.5SH_1x26-1MP_P0.50mm_Horizontal; LCSC C262277
J5: Conn_01x03; JST_EH_S3B-EH_1x03_P2.50mm_Horizontal; LCSC C263754
JP1: SolderJumper-2_P1.3mm_Bridged_RoundedPad1.0x1.5mm
L1: 10uH; L_0603_1608Metric
L4: 1uH; L_0603_1608Metric
L5, L6: 470nH; L_0603_1608Metric
L7: 60R / Short; L_0603_1608Metric; LCSC C85834
L8: EXC14CE900U; FILTER-SMD_4P-L0.9-W0.7-P0.50-BL; LCSC Part C178761
L9: 470nH; L_Murata_DFE201610P; LCSC C882980
Q4: SOT-523-3_L1.6-W0.8-P1.00-LS1.6-BR; Manufacturer Part DMN313DLT-7; LCSC C155524
Q5: SOT-363_L2.0-W1.3-P0.65-LS2.1-BL; Manufacturer Part MMDT2907A-7-F; LCSC C460232
Q6: SOT-23-3_L2.9-W1.3-P1.90-LS2.4-BR; Manufacturer Part DMP1045U-7; LCSC Part Name 1个P沟道 耐压:12V 电流:4A
R1, R2: 5.1K; R_0402_1005Metric
R9, R10, R11, R34, R36, R40, R41: 10K; R_0402_1005Metric
R31, R32: 1.5K; R_0402_1005Metric
R33: 4.7K; R_0402_1005Metric
R35: 100; R_0402_1005Metric
R37: 470; R_0402_1005Metric
R38: 30.1K; R_0402_1005Metric
R39: 5.23K; R_0402_1005Metric
R42: WW25WR010FTL; R2512; LCSC Part C171418
R43: DNP; R_0402_1005Metric
R44, R45: 1.5; R_0402_1005Metric
R46, R47: 3.3; R_0402_1005Metric
R48, R49: 100K; R_0402_1005Metric
R50: 10k; R_0402_1005Metric
R51: 400; R_0402_1005Metric
SW1, SW2: SW_Push; SW_SPST_CK_RS282G05A3; LCSC C318938
SW3: SKRTLAE010; KEY-SMD_SKRTLAE010; LCSC Part C110293
TP1, TP2, TP3: TestPoint; TestPoint_Pad_1.5x1.5mm
U1: STM32WB55RGV6; QFN-68-1EP_8x8mm_P0.4mm_EP6.4x6.4mm
U2: QFN-24_L4.0-W4.0-P0.50-TL-EP2.7; Manufacturer Part BQ25896RTWR; LCSC C181475
U4: DSBGA-9_L1.7-W1.6-R3-C3-P0.50-BL; Manufacturer Part BQ27220YZFR; LCSC C528617
U5: DSBGA-6_L1.4-W1.1-R3-C2-P0.40-BL; Manufacturer Part LM3281YFQR; LCSC C2070970
U7, U8, U9, U10, U11, U12: 74HC4051; TSSOP-16_4.4x5mm_P0.65mm
U13: SN74LV1T125DCKR; SC-70-5_L2.1-W1.3-P0.65-LS2.1-TL; LCSC Part C75925
U14: USBLC6-2P6; SOT-666
U15: FAN48610BUC50X; WLCSP-9_L1.2-W1.2-R3-C3-P0.40-BL; LCSC Part C890711
U16: RS3221-3.3YUTDN4; UTDFN-4_L1.0-W1.0-P0.63-BL-EP-1; LCSC C2924279
USB1: TYPE-C 16PIN 2MD(073); USB-C-SMD_TYPE-C-6PIN-2MD-073; LCSC Part C2765186
X1: XL7EL89CKI-111YLC-32M; CRYSTAL-SMD_4P-L2.0-W1.6-BL; LCSC Part C2965582
X2: FC-12M32.768KHZ7PF20PPM; FC-12M_L2.0-W1.2; LCSC Part C99009

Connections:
+3.3V: C2.1, C3.1, C4.1, C5.1, C6.1, C11.1, C12.1, C13.1, C14.1, C71.1, D4.2 (A), FB4.2, R9.1, R11.1, R31.2, R32.2, R33.2, R40.2, R46.1, R47.1, SW2.2, U1.30 (VDD), U1.33 (VDDRF), U1.44 (VDDSMPS), U1.45 (VDD), U1.55 (VDDUSB), U1.68 (VDD)
+5V: C45.1, C48.2, C50.2, C52.2, FB5.2, U7.16 (VCC), U8.16 (VCC), U9.16 (VCC), U10.16 (VCC), U11.16 (VCC), U12.16 (VCC), U15.A1 (VOUT), U15.A2 (VOUT)
+BATT: C65.1, J5.1, R42.2, TP1.1, U4.C1 (SRP), U4.C3 (BAT)
/ABUS: C18.1, C19.1, L7.2, U7.3 (A), U8.3 (A), U9.3 (A), U10.3 (A), U11.3 (A), U12.3 (A); also elsewhere on the board
/ADC1_IN3: U1.11 (PC2); also elsewhere on the board
/CPH1: C22.1, C23.1; also elsewhere on the board
/CPH2: C24.1, C25.1; also elsewhere on the board
/D+: L8.2, U1.52 (PA11)
/D-: L8.1, U1.53 (PA12)
/DRV_A: R51.2, U13.2 (A)
/EXCITER: C18.2, C19.2, R51.1, U1.66 (PB6)
/S0: U1.58 (PC10), U7.11 (S0), U8.11 (S0), U9.11 (S0), U10.11 (S0), U11.11 (S0), U12.11 (S0)
/S1: U1.57 (PA15), U7.10 (S1), U8.10 (S1), U9.10 (S1), U10.10 (S1), U11.10 (S1), U12.10 (S1)
/S2: U1.56 (PA14), U7.9 (S2), U8.9 (S2), U9.9 (S2), U10.9 (S2), U11.9 (S2), U12.9 (S2)
/TIM1_CH1: C22.2, U1.23 (PA8)
/TIM1_CH3: C23.2, U1.51 (PA10)
/TIM2_CH1: U1.15 (PA0); also elsewhere on the board
/TIM2_CH2: U1.16 (PA1); also elsewhere on the board
/TIM2_CH3: U1.17 (PA2); also elsewhere on the board
/TX_EN: D12.3 (COM), R50.1, U1.46 (PB12)
/X0: J3.26, U7.14 (A1)
/X1: J3.25, U7.15 (A2)
/X2: J3.23, U7.1 (A4)
/X3: J3.22, U7.2 (A6)
/X4: J3.21, U7.4 (A7)
/X5: J3.20, U7.5 (A5)
/X6: J3.18, U8.12 (A3)
/X7: J3.17, U8.13 (A0)
/X8: J3.16, U8.14 (A1)
/X9: J3.15, U8.15 (A2)
/X10: J3.13, U8.1 (A4)
/X11: J3.12, U8.2 (A6)
/X12: J3.11, U8.4 (A7)
/X13: J3.10, U8.5 (A5)
/X14: J3.8, U9.12 (A3)
/X15: J3.7, U9.13 (A0)
/X16: J3.6, U9.14 (A1)
/X17: J3.5, U9.15 (A2)
/X18: J3.3, U9.1 (A4)
/X19: J3.2, U9.2 (A6)
/X20: J4.26, U9.4 (A7)
/X21: J4.25, U9.5 (A5)
/X22: J4.23, U10.12 (A3)
/X23: J4.22, U10.13 (A0)
/X24: J4.21, U10.14 (A1)
/X25: J4.20, U10.15 (A2)
/X26: J4.18, U10.1 (A4)
/X27: J4.17, U10.2 (A6)
/Y0: J2.26, U11.12 (A3)
/Y1: J2.25, U11.13 (A0)
/Y2: J2.23, U11.14 (A1)
/Y3: J2.22, U11.15 (A2)
/Y4: J2.21, U11.1 (A4)
/Y5: J2.20, U11.2 (A6)
/Y6: J2.18, U11.4 (A7)
/Y7: J2.17, U11.5 (A5)
/Y8: J2.16, U12.12 (A3)
/Y9: J2.15, U12.13 (A0)
/Y10: J2.13, U12.14 (A1)
/Y11: J2.12, U12.15 (A2)
/Y12: J2.11, U12.1 (A4)
/Y13: J2.10, U12.2 (A6)
/Y14: J2.8, U12.4 (A7)
/Y15: J2.7, U12.5 (A5)
/Y16: J2.6, U7.12 (A3)
/Y17: J2.5, U7.13 (A0)
/~DRV_OE: C72.2, D12.1 (A), R50.2, U13.1 (#OE)
/~E0: U1.65 (PB5), U7.6 (~E)
/~E1: U1.64 (PB4), U8.6 (~E)
/~E2: U1.63 (PB3), U9.6 (~E)
/~E3: U1.62 (PD1), U10.6 (~E)
/~E4: U1.61 (PD0), U11.6 (~E)
/~E5: U1.60 (PC12), U12.6 (~E)
/~TIM1_CH1: C24.2, U1.22 (PA7)
/~TIM1_CH3: C25.2, U1.49 (PB15)
BOOT: R10.2, SW2.1, U1.5 (PH3)
BUTTON: R11.2, SW3.2, U1.2 (PC13)
GND: C1.2, C2.2, C3.2, C4.2, C5.2, C6.2, C7.2, C8.2, C9.2, C10.2, C11.2, C12.2, C13.2, C14.2, C15.2, C20.2, C21.2, C44.2, C45.2, C55.2, C56.2, C57.2, C59.2, C60.2, C61.2, C62.2, C63.2, C64.2, C65.2, C66.2, C67.2, C68.2, C69.2, C70.2, C71.2, D3.1 (K), D4.1 (K), FB3.1, FL2.2 (GND4), FL2.4 (GND1), FL2.5 (GND2), FL2.6 (GND3), J5.3, Q4.2 (S), R1.2, R2.2, R10.1, R36.1, R37.1, R38.1, R41.1, R43.2, R48.2, R49.2, SW1.2, SW3.1, SW3.3, SW3.4, SW3.5, TP3.1, U1.32 (VSSRF), U1.42 (VSSSMPS), U1.69 (VSS), U2.2 (PSEL), U2.9 (CE), U2.17 (PGND), U2.18 (PGND), U2.25 (EPAD), U4.B2 (VSS), U5.C2 (GND), U14.2 (GND), U15.C1 (PGND), U15.C2 (PGND), U15.C3 (AGND), U16.2 (GND), U16.5 (EP), USB1.1 (GND), USB1.12 (GND), USB1.13 (SHELL), USB1.14 (SHELL), X1.2 (GND), X1.4 (GND); also elsewhere on the board
GNDS: J2.4, J2.9, J2.14, J2.19, J2.24, J3.4, J3.9, J3.14, J3.19, J3.24, J4.4, J4.9, J4.14, J4.19, J4.24, JP1.1 (A)
I2C_SCL: R31.1, U1.6 (PB8), U2.5 (SCL), U4.A3 (SCL)
I2C_SDA: R32.1, U1.7 (PB9), U2.6 (SDA), U4.A2 (SDA)
LDO_3.3V: U1.1 (VBAT), U16.1 (OUT)
unnamed: AE1.1 (ANT), FL2.1 (OUT)
unnamed: C16.2, C73.2, L7.1
unnamed: C58.1, L4.1, U2.19 (SW), U2.20 (SW)
unnamed: D1.2 (A), Q5.2 (B1), Q5.5 (B2)
unnamed: FL2.3 (IN), U1.31 (RF1)
unnamed: J5.2, R38.2, R39.2, R43.1, TP2.1, U2.11 (TS)
unnamed: L5.2, R44.2, R45.2
unnamed: L6.2, R46.2, R47.2
unnamed: L8.3, U14.6 (I/O1)
unnamed: L8.4, U14.4 (I/O2)
unnamed: L9.2, U15.B1 (SW), U15.B2 (SW)
unnamed: Q4.3 (D), R34.1, U2.8 (OTG)
unnamed: Q4.1 (G), R35.1, R36.2
unnamed: Q5.6 (C1), Q6.1 (G), R49.1
unnamed: Q5.3 (C2), R48.1
unnamed: U1.35 (OSC_IN), X1.3
unnamed: U1.34 (OSC_OUT), X1.1
unnamed: C21.1, U1.3 (PC14), X2.2 (OSC2)
unnamed: C20.1, U1.4 (PC15), X2.1 (OSC1)
unnamed: C15.1, L1.2, U1.41 (VFBSMPS)
unnamed: L1.1, U1.43 (VLXSMPS)
unnamed: C9.1, C10.1, U1.13 (VREF+)
unnamed: C58.2, U2.21 (BTST)
unnamed: R33.1, U2.7 (INT)
unnamed: R37.2, U2.10 (LIIM)
unnamed: C55.1, U2.23 (PMID)
unnamed: C57.1, R39.1, U2.22 (REGN)
unnamed: R41.2, U4.B1 (BIN)
unnamed: R40.1, U4.A1 (GPOUT)
unnamed: C63.1, C64.1, U4.B3 (VDD)
unnamed: C68.1, C69.1, C70.1, L6.1, R44.1, R45.1, U5.A1 (FB)
unnamed: L5.1, U5.B2 (SW)
unnamed: C74.1, C75.1, FB5.1, U13.5 (VCC)
unnamed: C16.1, C73.1, U13.4 (Y)
unnamed: C61.1, C62.1, C66.1, R42.1, U2.13 (BAT), U2.14 (BAT), U4.C2 (SRN), U16.3 (EN), U16.4 (IN)
unnamed: R1.1, USB1.4 (CC1)
unnamed: R2.1, USB1.10 (CC2)
unnamed: U14.3 (I/O2), USB1.5 (DN2), USB1.7 (DN1)
unnamed: U14.1 (I/O1), USB1.6 (DP1), USB1.8 (DP2)
RESET: R9.2, SW1.1, U1.8 (NRST), U2.12 (QON)
SYS: C44.1, C59.1, C60.1, C67.1, L4.2, L9.1, R34.2, U2.15 (SYS), U2.16 (SYS), U5.A2 (VIN), U5.B1 (MODE), U5.C1 (EN), U15.A3 (VIN), U15.B3 (EN)
USB_5V: C56.1, Q5.4 (E2), Q6.2 (S), U2.1 (VBUS)
VBUS: C1.1, D1.1 (K), D3.2 (A), Q5.1 (E1), Q6.3 (D), R35.2, U14.5 (VBUS), USB1.2 (VBUS), USB1.11 (VBUS)
VDDA: C7.1, C8.1, FB4.1, U1.14 (VDDA); also elsewhere on the board
VEE: C49.1, C51.1, C53.1, JP1.2 (B), U7.7 (VEE), U8.7 (VEE), U9.7 (VEE), U10.7 (VEE), U11.7 (VEE), U12.7 (VEE); also elsewhere on the board
VSSA: C48.1, C49.2, C50.1, C51.2, C52.1, C53.2, C72.1, C74.2, C75.2, FB3.2, U7.8 (GND), U8.8 (GND), U9.8 (GND), U10.8 (GND), U11.8 (GND), U12.8 (GND), U13.3 (GND); also elsewhere on the board

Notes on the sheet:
If using thermistor, remove R43

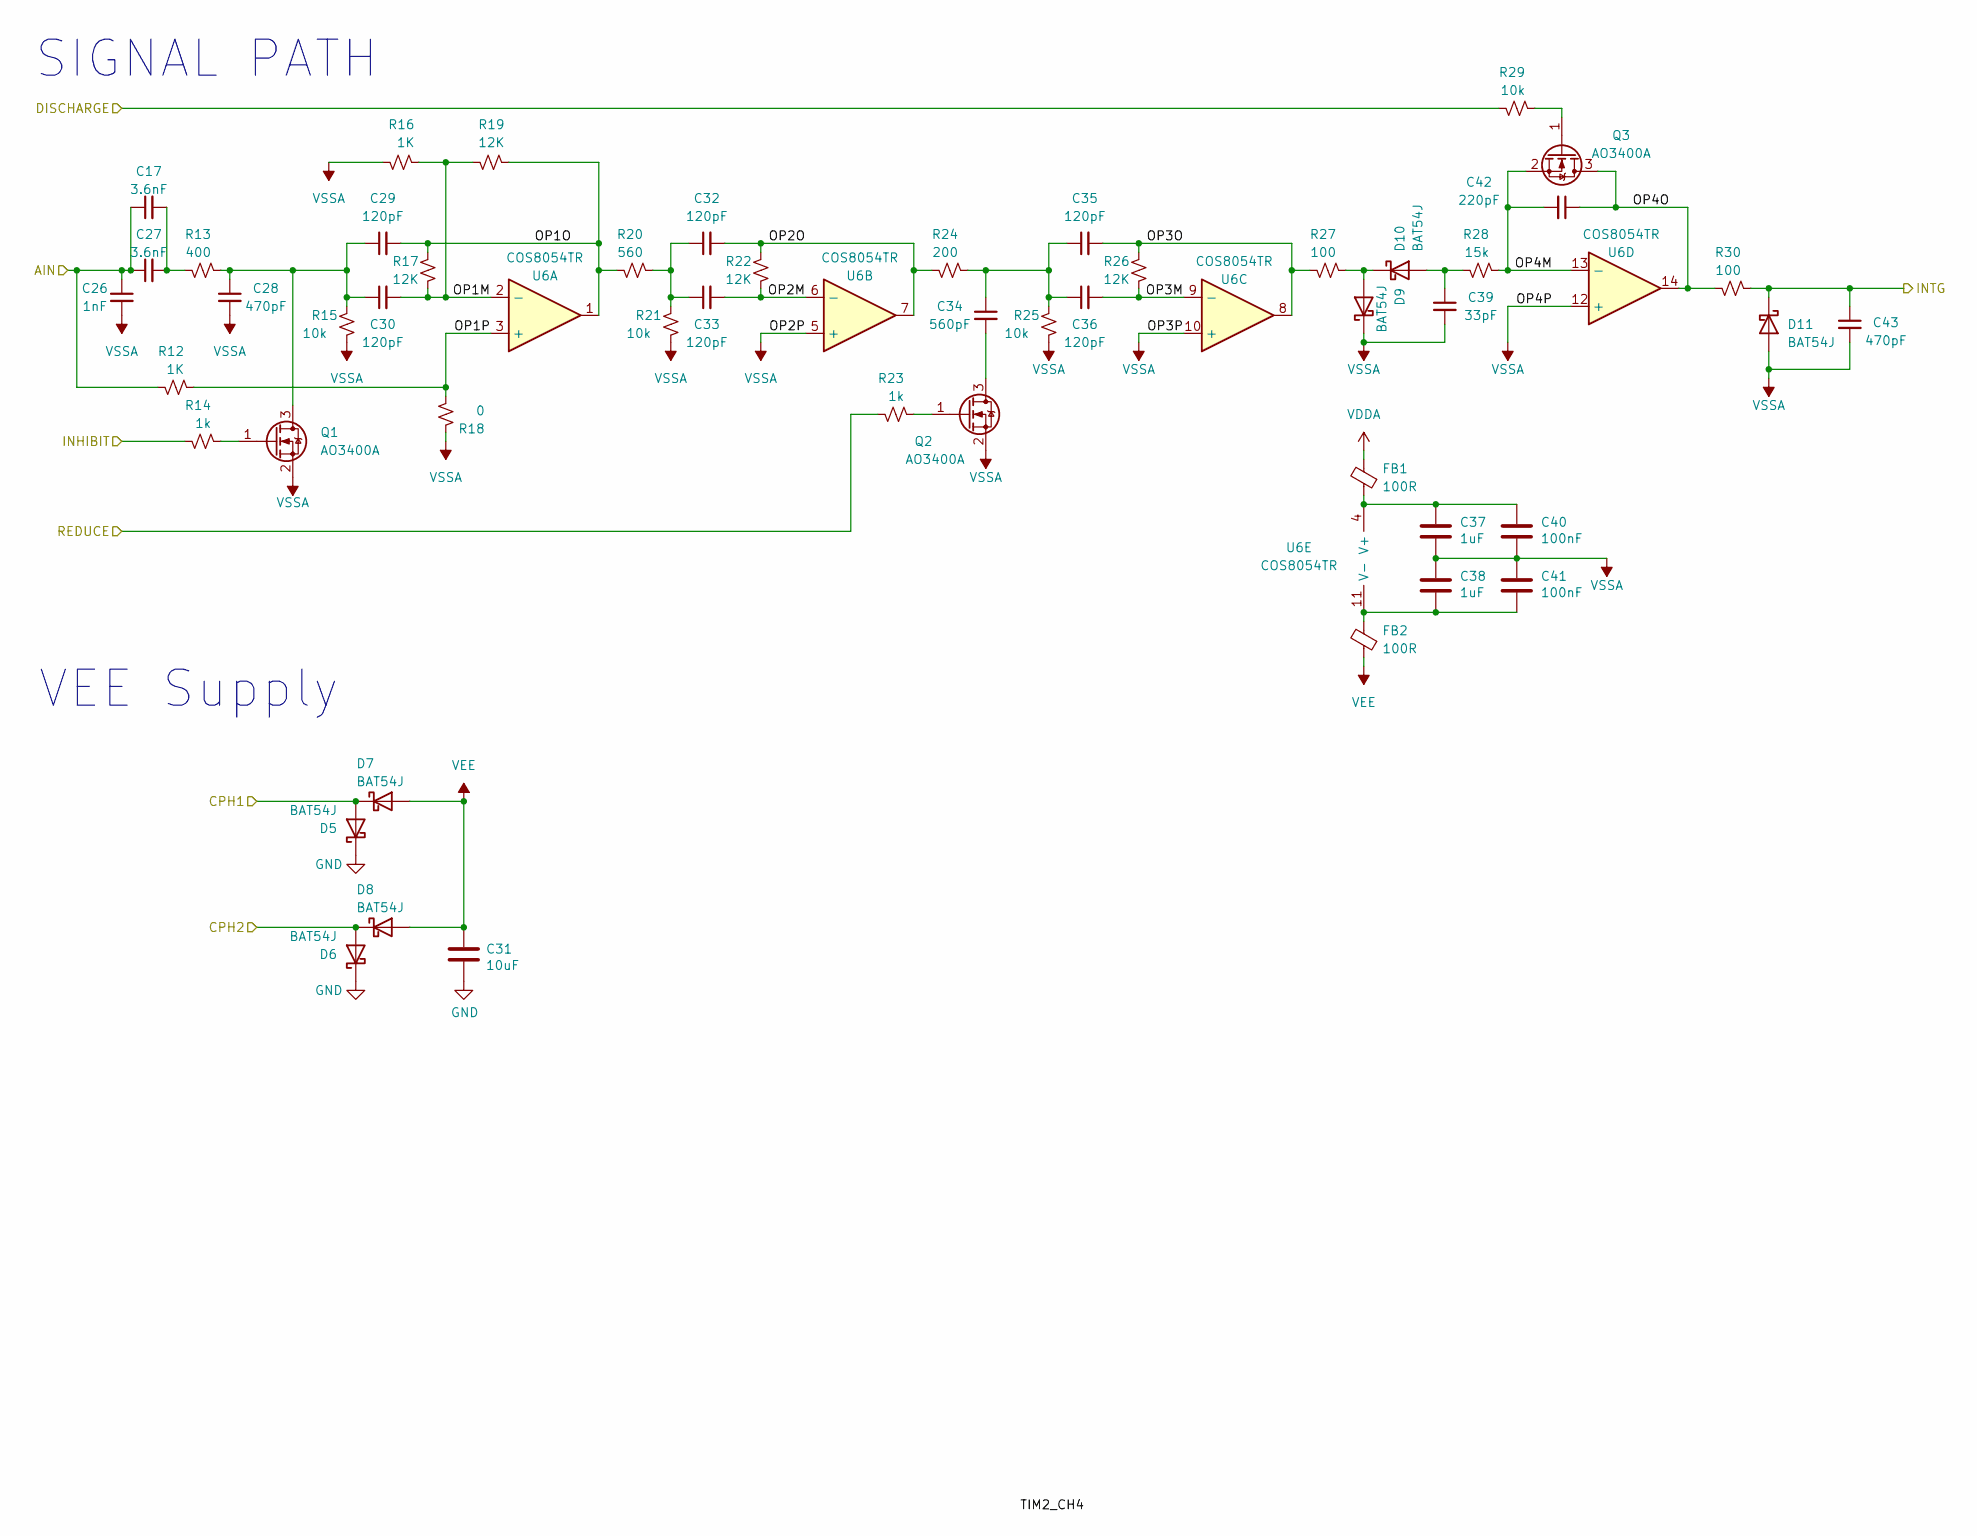
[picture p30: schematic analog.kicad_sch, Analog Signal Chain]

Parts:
C17, C27: 3.6nF; C_0603_1608Metric
C26: 1nF; C_0402_1005Metric
C28, C43: 470pF; C_0402_1005Metric
C29, C30, C32, C33, C35, C36: 120pF; C_0402_1005Metric
C31: 10uF; C_0402_1005Metric
C34: 560pF; C_0402_1005Metric
C37, C38: 1uF; C_0603_1608Metric
C39: 33pF; C_0402_1005Metric
C40, C41: 100nF; C_0603_1608Metric
C42: 220pF; C_0402_1005Metric
D5, D6, D7, D8, D9, D10, D11: BAT54J; D_SOD-323F
FB1, FB2: 100R; L_0603_1608Metric
Q1, Q2, Q3: AO3400A; SOT-23
R12, R16: 1K; R_0402_1005Metric
R13: 400; R_0402_1005Metric
R14, R23: 1k; R_0402_1005Metric
R15, R21, R25, R29: 10k; R_0402_1005Metric
R17, R19, R22, R26: 12K; R_0402_1005Metric
R18: 0; R_0402_1005Metric
R20: 560; R_0402_1005Metric
R24: 200; R_0402_1005Metric
R27, R30: 100; R_0402_1005Metric
R28: 15k; R_0402_1005Metric
U6: COS8054TR; TSSOP-14_4.4x5mm_P0.65mm

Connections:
/ABUS: C17.1, C26.1, C27.1, R12.1; also elsewhere on the board
/ADC1_IN3: C43.1, D11.1 (K), R30.2; also elsewhere on the board
/CPH1: D5.2 (A), D7.1 (K); also elsewhere on the board
/CPH2: D6.2 (A), D8.1 (K); also elsewhere on the board
/Signal Chain/OP1M: C30.2, R16.2, R17.1, R19.1, U6.2 (-)
/Signal Chain/OP1O: C29.2, R17.2, R19.2, R20.1, U6.1
/Signal Chain/OP1P: R12.2, R18.1, U6.3 (+)
/Signal Chain/OP2M: C33.2, R22.1, U6.6 (-)
/Signal Chain/OP2O: C32.2, R22.2, R24.1, U6.7
/Signal Chain/OP3M: C36.2, R26.1, U6.9 (-)
/Signal Chain/OP3O: C35.2, R26.2, R27.1, U6.8
/Signal Chain/OP4M: C42.2, Q3.2 (S), R28.2, U6.13 (-)
/Signal Chain/OP4O: C42.1, Q3.3 (D), R30.1, U6.14
/TIM2_CH1: R29.1; also elsewhere on the board
/TIM2_CH2: R23.1; also elsewhere on the board
/TIM2_CH3: R14.1; also elsewhere on the board
GND: C31.2, D5.1 (K), D6.1 (K); also elsewhere on the board
unnamed: C17.2, C27.2, R13.1
unnamed: C32.1, C33.1, R20.2, R21.2
unnamed: C34.1, C35.1, C36.1, R24.2, R25.2
unnamed: C39.1, D10.2 (A), R28.1
unnamed: D9.2 (A), D10.1 (K), R27.2
unnamed: C28.1, C29.1, C30.1, Q1.3 (D), R13.2, R15.2
unnamed: Q1.1 (G), R14.2
unnamed: C34.2, Q2.3 (D)
unnamed: Q2.1 (G), R23.2
unnamed: Q3.1 (G), R29.2
unnamed: C37.1, C40.1, FB1.1, U6.4 (V+)
unnamed: C38.2, C41.2, FB2.2, U6.11 (V-)
VDDA: FB1.2; also elsewhere on the board
VEE: C31.1, D7.2 (A), D8.2 (A), FB2.1; also elsewhere on the board
VSSA: C26.2, C28.2, C37.2, C38.1, C39.2, C40.2, C41.1, C43.2, D9.1 (K), D11.2 (A), Q1.2 (S), Q2.2 (S), R15.1, R16.1, R18.2, R21.1, R25.1, U6.5 (+), U6.10 (+), U6.12 (+); also elsewhere on the board

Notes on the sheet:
SIGNAL PATH
VEE Supply

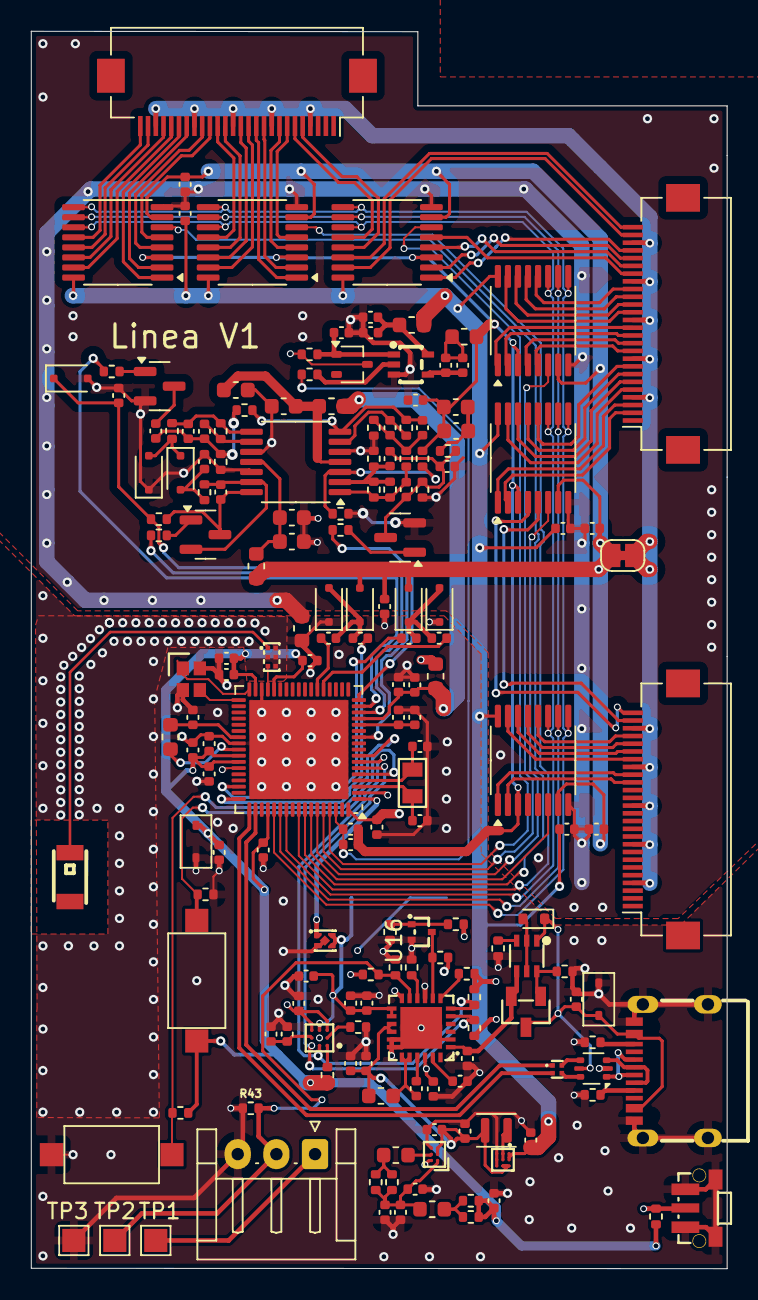
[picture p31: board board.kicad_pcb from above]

Board: 4 copper layers, 45.0 x 80.0 mm, 177 parts (1 on the bottom side), 149 nets.

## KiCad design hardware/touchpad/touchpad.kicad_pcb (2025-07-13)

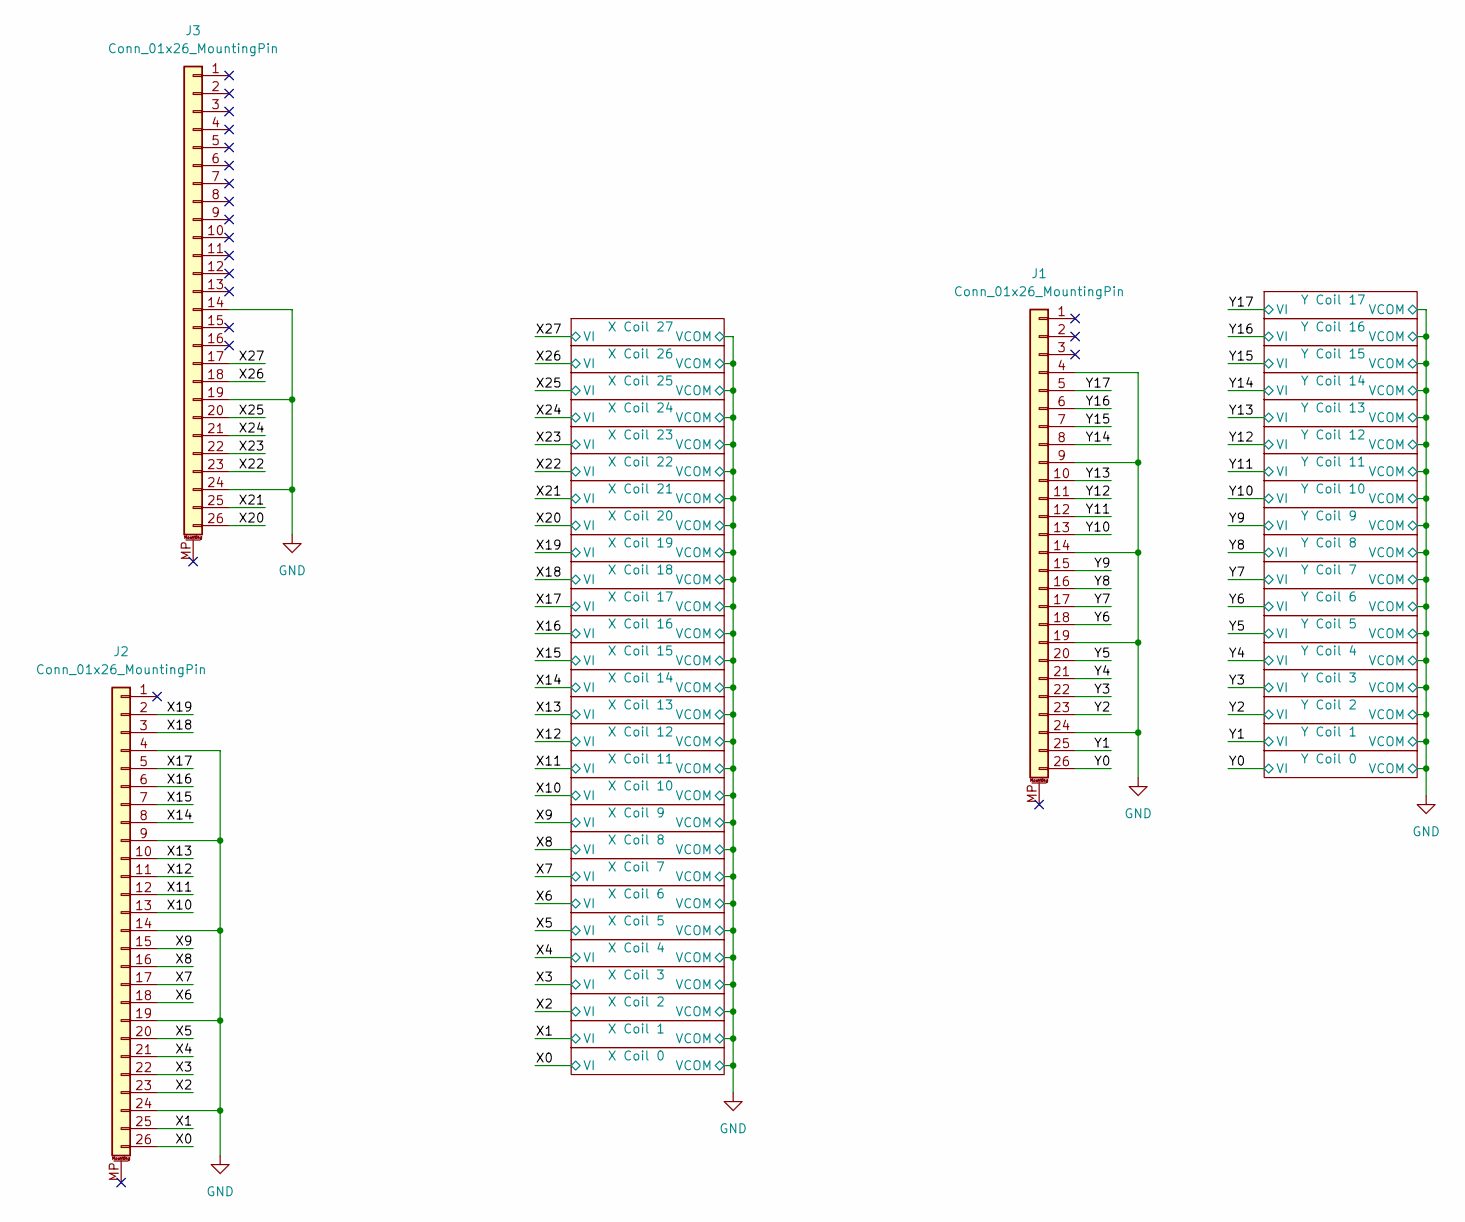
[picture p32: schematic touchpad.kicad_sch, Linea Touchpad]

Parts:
J1, J2, J3: Conn_01x26_MountingPin; Hirose_FH12-26S-0.5SH(55)-FPC_1

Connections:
/X0: J2.26; also elsewhere on the board
/X1: J2.25; also elsewhere on the board
/X2: J2.23; also elsewhere on the board
/X3: J2.22; also elsewhere on the board
/X4: J2.21; also elsewhere on the board
/X5: J2.20; also elsewhere on the board
/X6: J2.18; also elsewhere on the board
/X7: J2.17; also elsewhere on the board
/X8: J2.16; also elsewhere on the board
/X9: J2.15; also elsewhere on the board
/X10: J2.13; also elsewhere on the board
/X11: J2.12; also elsewhere on the board
/X12: J2.11; also elsewhere on the board
/X13: J2.10; also elsewhere on the board
/X14: J2.8; also elsewhere on the board
/X15: J2.7; also elsewhere on the board
/X16: J2.6; also elsewhere on the board
/X17: J2.5; also elsewhere on the board
/X18: J2.3; also elsewhere on the board
/X19: J2.2; also elsewhere on the board
/X20: J3.26; also elsewhere on the board
/X21: J3.25; also elsewhere on the board
/X22: J3.23; also elsewhere on the board
/X23: J3.22; also elsewhere on the board
/X24: J3.21; also elsewhere on the board
/X25: J3.20; also elsewhere on the board
/X26: J3.18; also elsewhere on the board
/X27: J3.17; also elsewhere on the board
/Y0: J1.26; also elsewhere on the board
/Y1: J1.25; also elsewhere on the board
/Y2: J1.23; also elsewhere on the board
/Y3: J1.22; also elsewhere on the board
/Y4: J1.21; also elsewhere on the board
/Y5: J1.20; also elsewhere on the board
/Y6: J1.18; also elsewhere on the board
/Y7: J1.17; also elsewhere on the board
/Y8: J1.16; also elsewhere on the board
/Y9: J1.15; also elsewhere on the board
/Y10: J1.13; also elsewhere on the board
/Y11: J1.12; also elsewhere on the board
/Y12: J1.11; also elsewhere on the board
/Y13: J1.10; also elsewhere on the board
/Y14: J1.8; also elsewhere on the board
/Y15: J1.7; also elsewhere on the board
/Y16: J1.6; also elsewhere on the board
/Y17: J1.5; also elsewhere on the board
GND: J1.4, J1.9, J1.14, J1.19, J1.24, J2.4, J2.9, J2.14, J2.19, J2.24, J3.14, J3.19, J3.24; also elsewhere on the board

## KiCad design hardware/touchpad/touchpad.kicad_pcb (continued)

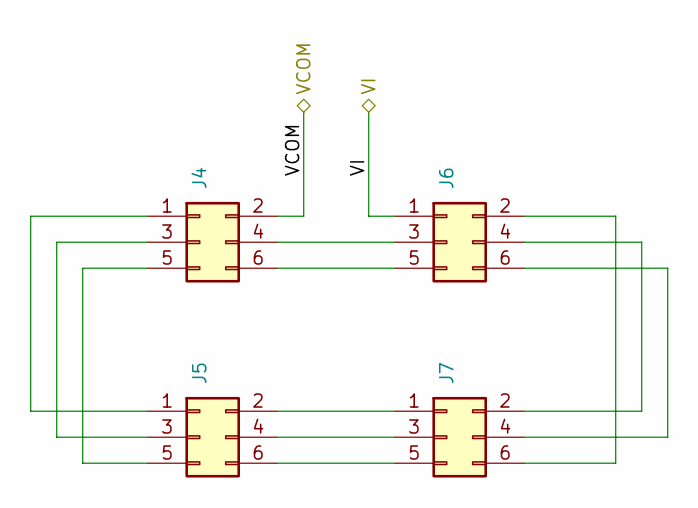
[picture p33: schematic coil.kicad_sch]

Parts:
J4, J5, J6, J7: Conn_02x03_Odd_Even; coil_terminal_3p

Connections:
/X0: J6.1; also elsewhere on the board
GND: J4.2; also elsewhere on the board
unnamed: J4.1, J5.1
unnamed: J4.3, J5.3
unnamed: J4.4, J6.3
unnamed: J4.5, J5.5
unnamed: J4.6, J6.5
unnamed: J5.2, J7.1
unnamed: J5.4, J7.3
unnamed: J5.6, J7.5
unnamed: J6.2, J7.6
unnamed: J6.4, J7.2
unnamed: J6.6, J7.4

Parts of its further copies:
J8, J9, J10, J11, J12, J13, J14, J15, J16, J17, J18, J19, J20, J21, J22, J23, J24, J25, J26, J27, J28, J29, J30, J31, J32, J33, J34, J35, J36, J37, J38, J39, J40, J41, J42, J43, J44, J45, J46, J47, J48, J49, J50, J51, J52, J53, J54, J55, J56, J57, J58, J59, J60, J61, J62, J63, J64, J65, J66, J67, J68, J69, J70, J71, J72, J73, J74, J75, J76, J77, J78, J79, J80, J81, J82, J83, J84, J85, J86, J87, J88, J89, J90, J91, J92, J93, J94, J95, J96, J97, J98, J99, J100, J101, J102, J103, J104, J105, J106, J107, J108, J109, J110, J111, J112, J113, J114, J115, J116, J117, J118, J119, J120, J121, J122, J123, J124, J125, J126, J127, J128, J129, J130, J131, J132, J133, J134, J135, J136, J137, J138, J139, J140, J141, J142, J143, J144, J145, J146, J147, J148, J149, J150, J151, J152, J153, J154, J155, J156, J157, J158, J159, J160, J161, J162, J163, J164, J165, J166, J167, J168, J169, J170, J171, J172, J173, J174, J175, J176, J177, J178, J179, J180, J181, J182, J183, J184, J185, J186, J187: Conn_02x03_Odd_Even; coil_terminal_3p

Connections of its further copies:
/X1: J10.1; also elsewhere on the board
/X2: J14.1; also elsewhere on the board
/X3: J18.1; also elsewhere on the board
/X4: J22.1; also elsewhere on the board
/X5: J26.1; also elsewhere on the board
/X6: J30.1; also elsewhere on the board
/X7: J34.1; also elsewhere on the board
/X8: J38.1; also elsewhere on the board
/X9: J42.1; also elsewhere on the board
/X10: J46.1; also elsewhere on the board
/X11: J186.1; also elsewhere on the board
/X12: J50.1; also elsewhere on the board
/X13: J54.1; also elsewhere on the board
/X14: J58.1; also elsewhere on the board
/X15: J62.1; also elsewhere on the board
/X16: J66.1; also elsewhere on the board
/X17: J70.1; also elsewhere on the board
/X18: J74.1; also elsewhere on the board
/X19: J78.1; also elsewhere on the board
/X20: J82.1; also elsewhere on the board
/X21: J86.1; also elsewhere on the board
/X22: J90.1; also elsewhere on the board
/X23: J94.1; also elsewhere on the board
/X24: J98.1; also elsewhere on the board
/X25: J102.1; also elsewhere on the board
/X26: J106.1; also elsewhere on the board
/X27: J110.1; also elsewhere on the board
/Y0: J114.1; also elsewhere on the board
/Y1: J118.1; also elsewhere on the board
/Y2: J122.1; also elsewhere on the board
/Y3: J126.1; also elsewhere on the board
/Y4: J130.1; also elsewhere on the board
/Y5: J134.1; also elsewhere on the board
/Y6: J138.1; also elsewhere on the board
/Y7: J142.1; also elsewhere on the board
/Y8: J146.1; also elsewhere on the board
/Y9: J150.1; also elsewhere on the board
/Y10: J154.1; also elsewhere on the board
/Y11: J158.1; also elsewhere on the board
/Y12: J162.1; also elsewhere on the board
/Y13: J166.1; also elsewhere on the board
/Y14: J170.1; also elsewhere on the board
/Y15: J174.1; also elsewhere on the board
/Y16: J178.1; also elsewhere on the board
/Y17: J182.1; also elsewhere on the board
GND: J8.2, J12.2, J16.2, J20.2, J24.2, J28.2, J32.2, J36.2, J40.2, J44.2, J48.2, J52.2, J56.2, J60.2, J64.2, J68.2, J72.2, J76.2, J80.2, J84.2, J88.2, J92.2, J96.2, J100.2, J104.2, J108.2, J112.2, J116.2, J120.2, J124.2, J128.2, J132.2, J136.2, J140.2, J144.2, J148.2, J152.2, J156.2, J160.2, J164.2, J168.2, J172.2, J176.2, J180.2, J184.2; also elsewhere on the board
unnamed: J8.1, J9.1
unnamed: J8.3, J9.3
unnamed: J8.5, J9.5
unnamed: J10.2, J11.6
unnamed: J8.4, J10.3
unnamed: J10.4, J11.2
unnamed: J8.6, J10.5
unnamed: J10.6, J11.4
unnamed: J9.2, J11.1
unnamed: J9.4, J11.3
unnamed: J9.6, J11.5
unnamed: J12.1, J13.1
unnamed: J12.3, J13.3
unnamed: J12.4, J14.3
unnamed: J12.5, J13.5
unnamed: J12.6, J14.5
unnamed: J13.2, J15.1
unnamed: J13.4, J15.3
unnamed: J13.6, J15.5
unnamed: J14.2, J15.6
unnamed: J14.4, J15.2
unnamed: J14.6, J15.4
unnamed: J16.1, J17.1
unnamed: J16.3, J17.3
unnamed: J16.4, J18.3
unnamed: J16.5, J17.5
unnamed: J16.6, J18.5
unnamed: J17.2, J19.1
unnamed: J17.4, J19.3
unnamed: J17.6, J19.5
unnamed: J18.2, J19.6
unnamed: J18.4, J19.2
unnamed: J18.6, J19.4
unnamed: J20.1, J21.1
unnamed: J20.3, J21.3
unnamed: J20.4, J22.3
unnamed: J20.5, J21.5
unnamed: J20.6, J22.5
unnamed: J21.2, J23.1
unnamed: J21.4, J23.3
unnamed: J21.6, J23.5
unnamed: J22.2, J23.6
unnamed: J22.4, J23.2
unnamed: J22.6, J23.4
unnamed: J24.1, J25.1
unnamed: J24.3, J25.3
unnamed: J24.4, J26.3
unnamed: J24.5, J25.5
unnamed: J24.6, J26.5
unnamed: J25.2, J27.1
unnamed: J25.4, J27.3
unnamed: J25.6, J27.5
unnamed: J26.2, J27.6
unnamed: J26.4, J27.2
unnamed: J26.6, J27.4
unnamed: J28.1, J29.1
unnamed: J28.3, J29.3
unnamed: J28.4, J30.3
unnamed: J28.5, J29.5
unnamed: J28.6, J30.5
unnamed: J29.2, J31.1
unnamed: J29.4, J31.3
unnamed: J29.6, J31.5
unnamed: J30.2, J31.6
unnamed: J30.4, J31.2
unnamed: J30.6, J31.4
unnamed: J32.1, J33.1
unnamed: J32.3, J33.3
unnamed: J32.4, J34.3
unnamed: J32.5, J33.5
unnamed: J32.6, J34.5
unnamed: J33.2, J35.1
unnamed: J33.4, J35.3
unnamed: J33.6, J35.5
unnamed: J34.2, J35.6
unnamed: J34.4, J35.2
unnamed: J34.6, J35.4
unnamed: J36.1, J37.1
unnamed: J36.3, J37.3
unnamed: J36.4, J38.3
unnamed: J36.5, J37.5
unnamed: J36.6, J38.5
unnamed: J37.2, J39.1
unnamed: J37.4, J39.3
unnamed: J37.6, J39.5
unnamed: J38.2, J39.6
unnamed: J38.4, J39.2
unnamed: J38.6, J39.4
unnamed: J40.1, J41.1
unnamed: J40.3, J41.3
unnamed: J40.4, J42.3
unnamed: J40.5, J41.5
unnamed: J40.6, J42.5
unnamed: J41.2, J43.1
unnamed: J41.4, J43.3
unnamed: J41.6, J43.5
unnamed: J42.2, J43.6
unnamed: J42.4, J43.2
unnamed: J42.6, J43.4
unnamed: J44.1, J45.1
unnamed: J44.3, J45.3
unnamed: J44.4, J46.3
unnamed: J44.5, J45.5
unnamed: J44.6, J46.5
unnamed: J45.2, J47.1
unnamed: J45.4, J47.3
unnamed: J45.6, J47.5
unnamed: J46.2, J47.6
unnamed: J46.4, J47.2
unnamed: J46.6, J47.4
unnamed: J48.1, J49.1
unnamed: J48.3, J49.3
unnamed: J48.4, J50.3
unnamed: J48.5, J49.5
unnamed: J48.6, J50.5
unnamed: J49.2, J51.1
unnamed: J49.4, J51.3
unnamed: J49.6, J51.5
unnamed: J50.2, J51.6
unnamed: J50.4, J51.2
unnamed: J50.6, J51.4
unnamed: J52.1, J53.1
unnamed: J52.3, J53.3
unnamed: J52.4, J54.3
unnamed: J52.5, J53.5
unnamed: J52.6, J54.5
unnamed: J53.2, J55.1
unnamed: J53.4, J55.3
unnamed: J53.6, J55.5
unnamed: J54.2, J55.6
unnamed: J54.4, J55.2
unnamed: J54.6, J55.4
unnamed: J56.1, J57.1
unnamed: J56.3, J57.3
unnamed: J56.4, J58.3
unnamed: J56.5, J57.5
unnamed: J56.6, J58.5
unnamed: J57.2, J59.1
unnamed: J57.4, J59.3
unnamed: J57.6, J59.5
unnamed: J58.2, J59.6
unnamed: J58.4, J59.2
unnamed: J58.6, J59.4
unnamed: J60.1, J61.1
unnamed: J60.3, J61.3
unnamed: J60.4, J62.3
unnamed: J60.5, J61.5
unnamed: J60.6, J62.5
unnamed: J61.2, J63.1
unnamed: J61.4, J63.3
unnamed: J61.6, J63.5
unnamed: J62.2, J63.6
unnamed: J62.4, J63.2
unnamed: J62.6, J63.4
unnamed: J64.1, J65.1
unnamed: J64.3, J65.3
unnamed: J64.4, J66.3
unnamed: J64.5, J65.5
unnamed: J64.6, J66.5
unnamed: J65.2, J67.1
unnamed: J65.4, J67.3
unnamed: J65.6, J67.5
unnamed: J66.2, J67.6
unnamed: J66.4, J67.2
unnamed: J66.6, J67.4
unnamed: J68.1, J69.1
unnamed: J68.3, J69.3
unnamed: J68.4, J70.3
unnamed: J68.5, J69.5
unnamed: J68.6, J70.5
unnamed: J69.2, J71.1
unnamed: J69.4, J71.3
unnamed: J69.6, J71.5
unnamed: J70.2, J71.6
unnamed: J70.4, J71.2
unnamed: J70.6, J71.4
unnamed: J72.1, J73.1
unnamed: J72.3, J73.3
unnamed: J72.4, J74.3
unnamed: J72.5, J73.5
unnamed: J72.6, J74.5
unnamed: J73.2, J75.1
unnamed: J73.4, J75.3
unnamed: J73.6, J75.5
unnamed: J74.2, J75.6
unnamed: J74.4, J75.2
unnamed: J74.6, J75.4
unnamed: J76.1, J77.1
unnamed: J76.3, J77.3
unnamed: J76.4, J78.3
unnamed: J76.5, J77.5
unnamed: J76.6, J78.5
unnamed: J77.2, J79.1
unnamed: J77.4, J79.3
unnamed: J77.6, J79.5
unnamed: J78.2, J79.6
unnamed: J78.4, J79.2
unnamed: J78.6, J79.4
unnamed: J80.1, J81.1
unnamed: J80.3, J81.3
unnamed: J80.4, J82.3
unnamed: J80.5, J81.5
unnamed: J80.6, J82.5
unnamed: J81.2, J83.1
unnamed: J81.4, J83.3
unnamed: J81.6, J83.5
unnamed: J82.2, J83.6
unnamed: J82.4, J83.2
unnamed: J82.6, J83.4
unnamed: J84.1, J85.1
unnamed: J84.3, J85.3
unnamed: J84.4, J86.3
unnamed: J84.5, J85.5
unnamed: J84.6, J86.5
unnamed: J85.2, J87.1
unnamed: J85.4, J87.3
unnamed: J85.6, J87.5
unnamed: J86.2, J87.6
unnamed: J86.4, J87.2
unnamed: J86.6, J87.4
unnamed: J88.1, J89.1
unnamed: J88.3, J89.3
unnamed: J88.4, J90.3
unnamed: J88.5, J89.5
unnamed: J88.6, J90.5
unnamed: J89.2, J91.1
unnamed: J89.4, J91.3
unnamed: J89.6, J91.5
unnamed: J90.2, J91.6
unnamed: J90.4, J91.2
unnamed: J90.6, J91.4
unnamed: J92.1, J93.1
unnamed: J92.3, J93.3
unnamed: J92.4, J94.3
unnamed: J92.5, J93.5
unnamed: J92.6, J94.5
unnamed: J93.2, J95.1
unnamed: J93.4, J95.3
unnamed: J93.6, J95.5
unnamed: J94.2, J95.6
unnamed: J94.4, J95.2
unnamed: J94.6, J95.4
unnamed: J96.1, J97.1
unnamed: J96.3, J97.3
unnamed: J96.4, J98.3
unnamed: J96.5, J97.5
unnamed: J96.6, J98.5
unnamed: J97.2, J99.1
unnamed: J97.4, J99.3
unnamed: J97.6, J99.5
unnamed: J98.2, J99.6
unnamed: J98.4, J99.2
unnamed: J98.6, J99.4
unnamed: J100.1, J101.1
unnamed: J100.3, J101.3
unnamed: J100.4, J102.3
unnamed: J100.5, J101.5
unnamed: J100.6, J102.5
unnamed: J101.2, J103.1
unnamed: J101.4, J103.3
unnamed: J101.6, J103.5
unnamed: J102.2, J103.6
unnamed: J102.4, J103.2
unnamed: J102.6, J103.4
unnamed: J104.1, J105.1
unnamed: J104.3, J105.3
unnamed: J104.4, J106.3
unnamed: J104.5, J105.5
unnamed: J104.6, J106.5
unnamed: J105.2, J107.1
unnamed: J105.4, J107.3
unnamed: J105.6, J107.5
unnamed: J106.2, J107.6
unnamed: J106.4, J107.2
unnamed: J106.6, J107.4
unnamed: J108.1, J109.1
unnamed: J108.3, J109.3
unnamed: J108.4, J110.3
unnamed: J108.5, J109.5
unnamed: J108.6, J110.5
unnamed: J109.2, J111.1
unnamed: J109.4, J111.3
unnamed: J109.6, J111.5
unnamed: J110.2, J111.6
unnamed: J110.4, J111.2
unnamed: J110.6, J111.4
unnamed: J112.1, J113.1
unnamed: J112.3, J113.3
unnamed: J112.4, J114.3
unnamed: J112.5, J113.5
unnamed: J112.6, J114.5
unnamed: J113.2, J115.1
unnamed: J113.4, J115.3
unnamed: J113.6, J115.5
unnamed: J114.2, J115.6
unnamed: J114.4, J115.2
unnamed: J114.6, J115.4
unnamed: J116.1, J117.1
unnamed: J116.3, J117.3
unnamed: J116.4, J118.3
unnamed: J116.5, J117.5
unnamed: J116.6, J118.5
unnamed: J117.2, J119.1
unnamed: J117.4, J119.3
unnamed: J117.6, J119.5
unnamed: J118.2, J119.6
unnamed: J118.4, J119.2
unnamed: J118.6, J119.4
unnamed: J120.1, J121.1
unnamed: J120.3, J121.3
unnamed: J120.4, J122.3
unnamed: J120.5, J121.5
unnamed: J120.6, J122.5
unnamed: J121.2, J123.1
unnamed: J121.4, J123.3
unnamed: J121.6, J123.5
unnamed: J122.2, J123.6
unnamed: J122.4, J123.2
unnamed: J122.6, J123.4
unnamed: J124.1, J125.1
unnamed: J124.3, J125.3
unnamed: J124.4, J126.3
unnamed: J124.5, J125.5
unnamed: J124.6, J126.5
unnamed: J125.2, J127.1
unnamed: J125.4, J127.3
unnamed: J125.6, J127.5
unnamed: J126.2, J127.6
unnamed: J126.4, J127.2
unnamed: J126.6, J127.4
unnamed: J128.1, J129.1
unnamed: J128.3, J129.3
unnamed: J128.4, J130.3
unnamed: J128.5, J129.5
unnamed: J128.6, J130.5
unnamed: J129.2, J131.1
unnamed: J129.4, J131.3
unnamed: J129.6, J131.5
unnamed: J130.2, J131.6
unnamed: J130.4, J131.2
unnamed: J130.6, J131.4
unnamed: J132.1, J133.1
unnamed: J132.3, J133.3
unnamed: J132.4, J134.3
unnamed: J132.5, J133.5
unnamed: J132.6, J134.5
unnamed: J133.2, J135.1
unnamed: J133.4, J135.3
unnamed: J133.6, J135.5
unnamed: J134.2, J135.6
unnamed: J134.4, J135.2
unnamed: J134.6, J135.4
unnamed: J136.1, J137.1
unnamed: J136.3, J137.3
unnamed: J136.4, J138.3
unnamed: J136.5, J137.5
unnamed: J136.6, J138.5
unnamed: J137.2, J139.1
unnamed: J137.4, J139.3
unnamed: J137.6, J139.5
unnamed: J138.2, J139.6
unnamed: J138.4, J139.2
unnamed: J138.6, J139.4
unnamed: J140.1, J141.1
unnamed: J140.3, J141.3
unnamed: J140.4, J142.3
unnamed: J140.5, J141.5
unnamed: J140.6, J142.5
unnamed: J141.2, J143.1
unnamed: J141.4, J143.3
unnamed: J141.6, J143.5
unnamed: J142.2, J143.6
unnamed: J142.4, J143.2
unnamed: J142.6, J143.4
unnamed: J144.1, J145.1
unnamed: J144.3, J145.3
unnamed: J144.4, J146.3
unnamed: J144.5, J145.5
unnamed: J144.6, J146.5
unnamed: J145.2, J147.1
unnamed: J145.4, J147.3
unnamed: J145.6, J147.5
unnamed: J146.2, J147.6
unnamed: J146.4, J147.2
unnamed: J146.6, J147.4
unnamed: J148.1, J149.1
unnamed: J148.3, J149.3
unnamed: J148.4, J150.3
unnamed: J148.5, J149.5
unnamed: J148.6, J150.5
unnamed: J149.2, J151.1
unnamed: J149.4, J151.3
unnamed: J149.6, J151.5
unnamed: J150.2, J151.6
unnamed: J150.4, J151.2
unnamed: J150.6, J151.4
unnamed: J152.1, J153.1
unnamed: J152.3, J153.3
unnamed: J152.4, J154.3
unnamed: J152.5, J153.5
unnamed: J152.6, J154.5
unnamed: J153.2, J155.1
unnamed: J153.4, J155.3
unnamed: J153.6, J155.5
unnamed: J154.2, J155.6
unnamed: J154.4, J155.2
unnamed: J154.6, J155.4
unnamed: J156.1, J157.1
unnamed: J156.3, J157.3
unnamed: J156.4, J158.3
unnamed: J156.5, J157.5
unnamed: J156.6, J158.5
unnamed: J157.2, J159.1
unnamed: J157.4, J159.3
unnamed: J157.6, J159.5
unnamed: J158.2, J159.6
unnamed: J158.4, J159.2
unnamed: J158.6, J159.4
unnamed: J160.1, J161.1
unnamed: J160.3, J161.3
unnamed: J160.4, J162.3
unnamed: J160.5, J161.5
unnamed: J160.6, J162.5
unnamed: J161.2, J163.1
unnamed: J161.4, J163.3
unnamed: J161.6, J163.5
unnamed: J162.2, J163.6
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

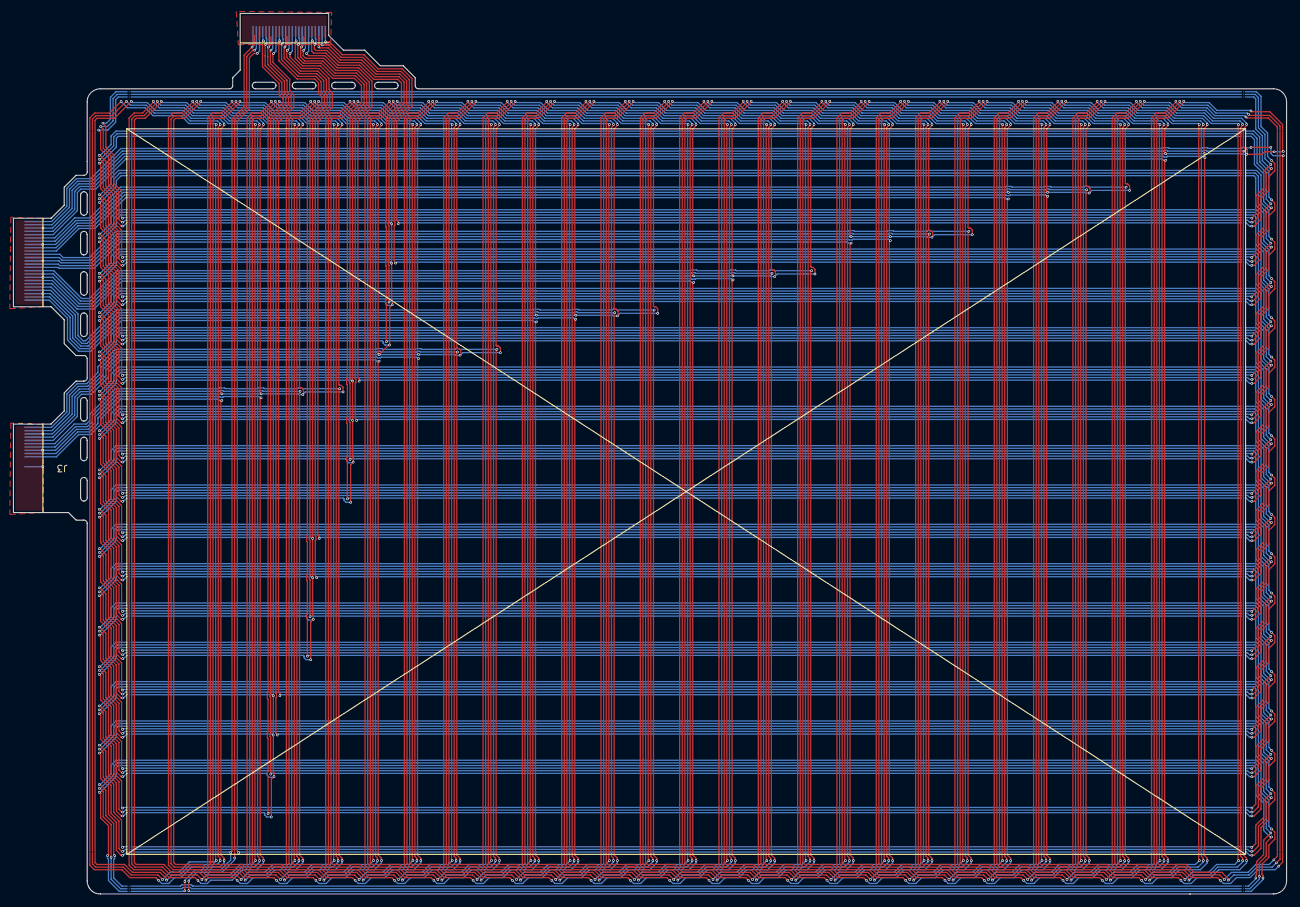
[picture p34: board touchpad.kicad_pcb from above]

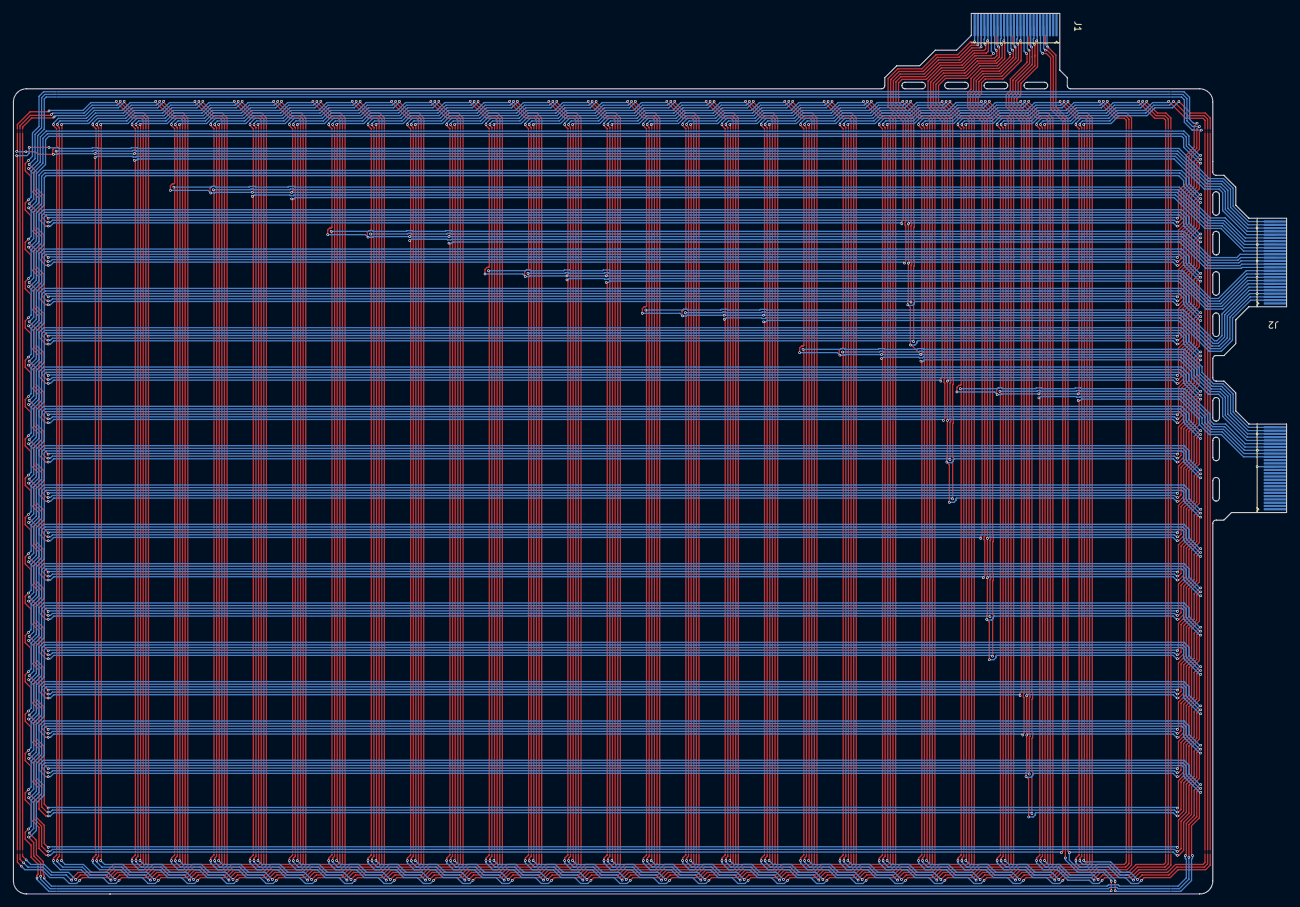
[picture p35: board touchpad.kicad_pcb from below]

Board: 2 copper layers, 194.2 x 134.4 mm, 187 parts (75 on the bottom side), 553 nets.

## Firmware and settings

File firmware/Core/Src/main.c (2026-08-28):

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
/* Includes ------------------------------------------------------------------*/
#include "main.h"
#include "adc.h"
#include "i2c.h"
#include "ipcc.h"
#include "memorymap.h"
#include "rf.h"
#include "rtc.h"
#include "tim.h"
#include "usart.h"
#include "usb_device.h"
#include "gpio.h"

/* USER CODE BEGIN Includes */
// #include "linea.h"
#include "stdio.h"
#include "patchouli_config.h"
#include "patchouli.h"
#include "usbd_cdc_if.h"

#define VERBOSE 1

#if defined(PATCHOULI_PCB_DISCRETE_SST)
  #include "patchouli_bsp_discrete_sst.h"
#elif defined(PATCHOULI_PCB_GLIDER_ADDON_V1)
  #include "patchouli_bsp_glider_addon_v1.h"
#endif
/* USER CODE END Includes */


void SystemClock_Config(void);
void PeriphCommonClock_Config(void);
/* USER CODE BEGIN 0 */
uint8_t usbhid_txbuf[12];
/* USER CODE END 0 */

/**
  * @brief  The application entry point.
  * @retval int
  */
int main(void)
{

  /* MCU Configuration--------------------------------------------------------*/

  /* Reset of all peripherals, Initializes the Flash interface and the Systick. */
  HAL_Init();
  /* Config code for STM32_WPAN (HSE Tuning must be done before system clock configuration) */
  MX_APPE_Config();

  /* Configure the system clock */
  SystemClock_Config();

  /* Configure the peripherals common clocks */
  PeriphCommonClock_Config();

  /* IPCC initialisation */
  MX_IPCC_Init();

  /* Initialize all configured peripherals */
  MX_GPIO_Init();
  MX_ADC1_Init();
  HAL_ADCEx_Calibration_Start(&hadc1, ADC_SINGLE_ENDED);
  MX_I2C1_Init();
  MX_TIM1_Init();
  MX_TIM16_Init();
  MX_USART1_UART_Init();
  MX_RTC_Init();
  MX_USB_Device_Init();
  MX_RF_Init();
  /* USER CODE BEGIN 2 */
    // CDC_Transmit_FS("Hello World", 12);
    MX_USB_Device_Init();
  HAL_Delay(1000);
  CDC_Transmit_FS("Hello World\n", 13);
  CDC_Transmit_FS("Hello Worldaa\n", 15);

  patchouli_init();
  patchouli_set_mode(PATCHOULI_DEBUG_NONE);
  HAL_Delay(1000);
  
  // CDC_Transmit_FS("Init Done\n", 11);
  // CDC_Transmit_FS("SYSCLK: ", 9);
  // char buf[10];
  // sprintf(buf, "%d", (int)(HAL_RCC_GetSysClockFreq()/1.0e6f));
  // CDC_Transmit_FS(buf, strlen(buf));
  // CDC_Transmit_FS(" MHz", 7);
  htim16.Instance->RCR=50;
  // PB6 (EXCITER) is TIM16_CH1N — don't reconfigure as GPIO or PWM stops
  CDC_Transmit_FS("Glider Addon Build2\n", 20);
  HAL_Delay(1000);
  CDC_Transmit_FS("Glider Addon Build3\n", 20);

  // ADC debug: test internal VREFINT and external PC2
  {
    ADC_ChannelConfTypeDef sConf = {0};

    // First: read internal VREFINT
    sConf.Channel = ADC_CHANNEL_VREFINT;
    sConf.Rank = ADC_REGULAR_RANK_1;
    sConf.SamplingTime = ADC_SAMPLETIME_247CYCLES_5;
    sConf.SingleDiff = ADC_SINGLE_ENDED;
    sConf.OffsetNumber = ADC_OFFSET_NONE;
    HAL_ADC_ConfigChannel(&hadc1, &sConf);
    HAL_ADC_Start(&hadc1);
    HAL_ADC_PollForConversion(&hadc1, HAL_MAX_DELAY);
    uint16_t vref = HAL_ADC_GetValue(&hadc1);

    // Then: read PC2 (channel 3)
    sConf.Channel = ADC_CHANNEL_3;
    HAL_ADC_ConfigChannel(&hadc1, &sConf);
    HAL_ADC_Start(&hadc1);
    HAL_ADC_PollForConversion(&hadc1, HAL_MAX_DELAY);
    uint16_t ch3 = HAL_ADC_GetValue(&hadc1);

    char dbg[64];
    sprintf(dbg, "VREF: %u  CH3: %u\n", vref, ch3);
    CDC_Transmit_FS((uint8_t*)dbg, strlen(dbg));
    HAL_Delay(500);
  }

  /* USER CODE END 2 */

  /* Init code for STM32_WPAN */
  MX_APPE_Init();

  /* Infinite loop */
  /* USER CODE BEGIN WHILE */
  while (1)
  {
    /* USER CODE END WHILE */
    MX_APPE_Process();

    /* USER CODE BEGIN 3 */
    // Process Linea library
    patchouli_cycle();
    // linea_cycle();
  }
  /* USER CODE END 3 */
}

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


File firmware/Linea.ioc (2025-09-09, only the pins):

Mcu.UserName=STM32WB55RGVx
PA0.GPIO_Label=DISCHARGE
PA0.Signal=GPIO_Output
PA1.Signal=S_TIM2_CH2
PA10.Signal=S_TIM1_CH3
PA11.Signal=USB_DM
PA12.Signal=USB_DP
PA14.GPIO_Label=S2
PA14.Signal=GPIO_Output
PA15.GPIO_Label=S1
PA15.Signal=GPIO_Output
PA2.Signal=S_TIM2_CH3
PA7.Signal=TIM1_CH1N
PA8.Signal=S_TIM1_CH1
PA9.Signal=USART1_TX
PB15.Signal=TIM1_CH3N
PB3.GPIO_Label=E2N
PB3.Signal=GPIO_Output
PB4.GPIO_Label=E1N
PB4.Signal=GPIO_Output
PB5.GPIO_Label=E0N
PB5.Signal=GPIO_Output
PB6.GPIO_Label=EXCITER
PB6.Signal=TIM16_CH1N
PB7.Signal=USART1_RX
PB8.Signal=I2C1_SCL
PB9.Signal=I2C1_SDA
PC10.GPIO_Label=S0
PC10.Signal=GPIO_Output
PC12.GPIO_Label=E5N
PC12.Signal=GPIO_Output
PC13.Signal=GPIO_Input
PC14-OSC32_IN.Signal=RCC_OSC32_IN
PC15-OSC32_OUT.Signal=RCC_OSC32_OUT
PC2.Signal=ADCx_IN3
PD0.GPIO_Label=E4N
PD0.Signal=GPIO_Output
PD1.GPIO_Label=E3N
PD1.Signal=GPIO_Output
PH3-BOOT0.Signal=GPIO_Input

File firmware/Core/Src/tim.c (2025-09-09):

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
/* Includes ------------------------------------------------------------------*/
#include "tim.h"

TIM_HandleTypeDef htim1;
TIM_HandleTypeDef htim16;

/* TIM1 init function */
void MX_TIM1_Init(void)
{

  TIM_ClockConfigTypeDef sClockSourceConfig = {0};
  TIM_MasterConfigTypeDef sMasterConfig = {0};
  TIM_OC_InitTypeDef sConfigOC = {0};
  TIM_BreakDeadTimeConfigTypeDef sBreakDeadTimeConfig = {0};

  htim1.Instance = TIM1;
  htim1.Init.Prescaler = 0;
  htim1.Init.CounterMode = TIM_COUNTERMODE_UP;
  htim1.Init.Period = 65535;
  htim1.Init.ClockDivision = TIM_CLOCKDIVISION_DIV1;
  htim1.Init.RepetitionCounter = 0;
  htim1.Init.AutoReloadPreload = TIM_AUTORELOAD_PRELOAD_DISABLE;
  if (HAL_TIM_Base_Init(&htim1) != HAL_OK)
  {
    Error_Handler();
  }
  sClockSourceConfig.ClockSource = TIM_CLOCKSOURCE_INTERNAL;
  if (HAL_TIM_ConfigClockSource(&htim1, &sClockSourceConfig) != HAL_OK)
  {
    Error_Handler();
  }
  if (HAL_TIM_PWM_Init(&htim1) != HAL_OK)
  {
    Error_Handler();
  }
  sMasterConfig.MasterOutputTrigger = TIM_TRGO_RESET;
  sMasterConfig.MasterOutputTrigger2 = TIM_TRGO2_RESET;
  sMasterConfig.MasterSlaveMode = TIM_MASTERSLAVEMODE_DISABLE;
  if (HAL_TIMEx_MasterConfigSynchronization(&htim1, &sMasterConfig) != HAL_OK)
  {
    Error_Handler();
  }
  sConfigOC.OCMode = TIM_OCMODE_PWM1;
  sConfigOC.Pulse = 0;
  sConfigOC.OCPolarity = TIM_OCPOLARITY_HIGH;
  sConfigOC.OCNPolarity = TIM_OCNPOLARITY_HIGH;
  sConfigOC.OCFastMode = TIM_OCFAST_DISABLE;
  sConfigOC.OCIdleState = TIM_OCIDLESTATE_RESET;
  sConfigOC.OCNIdleState = TIM_OCNIDLESTATE_RESET;
  if (HAL_TIM_PWM_ConfigChannel(&htim1, &sConfigOC, TIM_CHANNEL_1) != HAL_OK)
  {
    Error_Handler();
  }
  if (HAL_TIM_PWM_ConfigChannel(&htim1, &sConfigOC, TIM_CHANNEL_3) != HAL_OK)
  {
    Error_Handler();
  }
  sBreakDeadTimeConfig.OffStateRunMode = TIM_OSSR_DISABLE;
  sBreakDeadTimeConfig.OffStateIDLEMode = TIM_OSSI_DISABLE;
  sBreakDeadTimeConfig.LockLevel = TIM_LOCKLEVEL_OFF;
  sBreakDeadTimeConfig.DeadTime = 0;
  sBreakDeadTimeConfig.BreakState = TIM_BREAK_DISABLE;
  sBreakDeadTimeConfig.BreakPolarity = TIM_BREAKPOLARITY_HIGH;
  sBreakDeadTimeConfig.BreakFilter = 0;
  sBreakDeadTimeConfig.BreakAFMode = TIM_BREAK_AFMODE_INPUT;
  sBreakDeadTimeConfig.Break2State = TIM_BREAK2_DISABLE;
  sBreakDeadTimeConfig.Break2Polarity = TIM_BREAK2POLARITY_HIGH;
  sBreakDeadTimeConfig.Break2Filter = 0;
  sBreakDeadTimeConfig.Break2AFMode = TIM_BREAK_AFMODE_INPUT;
  sBreakDeadTimeConfig.AutomaticOutput = TIM_AUTOMATICOUTPUT_DISABLE;
  if (HAL_TIMEx_ConfigBreakDeadTime(&htim1, &sBreakDeadTimeConfig) != HAL_OK)
  {
    Error_Handler();
  }
  HAL_TIM_MspPostInit(&htim1);

}
/* TIM16 init function */
void MX_TIM16_Init(void)
{

  TIM_OC_InitTypeDef sConfigOC = {0};
  TIM_BreakDeadTimeConfigTypeDef sBreakDeadTimeConfig = {0};

  htim16.Instance = TIM16;
  htim16.Init.Prescaler = 0;
  htim16.Init.CounterMode = TIM_COUNTERMODE_UP;
  htim16.Init.Period = 65535;
  htim16.Init.ClockDivision = TIM_CLOCKDIVISION_DIV1;
  htim16.Init.RepetitionCounter = 0;
  htim16.Init.AutoReloadPreload = TIM_AUTORELOAD_PRELOAD_DISABLE;
  if (HAL_TIM_Base_Init(&htim16) != HAL_OK)
  {
    Error_Handler();
  }
  if (HAL_TIM_PWM_Init(&htim16) != HAL_OK)
  {
    Error_Handler();
  }
  if (HAL_TIM_OnePulse_Init(&htim16, TIM_OPMODE_SINGLE) != HAL_OK)
  {
    Error_Handler();
  }
  sConfigOC.OCMode = TIM_OCMODE_PWM1;
  sConfigOC.Pulse = 0;
  sConfigOC.OCPolarity = TIM_OCPOLARITY_HIGH;
  sConfigOC.OCNPolarity = TIM_OCNPOLARITY_HIGH;
  sConfigOC.OCFastMode = TIM_OCFAST_DISABLE;
  sConfigOC.OCIdleState = TIM_OCIDLESTATE_RESET;
  sConfigOC.OCNIdleState = TIM_OCNIDLESTATE_RESET;
  if (HAL_TIM_PWM_ConfigChannel(&htim16, &sConfigOC, TIM_CHANNEL_1) != HAL_OK)
  {
    Error_Handler();
  }
  sBreakDeadTimeConfig.OffStateRunMode = TIM_OSSR_DISABLE;
  sBreakDeadTimeConfig.OffStateIDLEMode = TIM_OSSI_DISABLE;
  sBreakDeadTimeConfig.LockLevel = TIM_LOCKLEVEL_OFF;
  sBreakDeadTimeConfig.DeadTime = 0;
  sBreakDeadTimeConfig.BreakState = TIM_BREAK_DISABLE;
  sBreakDeadTimeConfig.BreakPolarity = TIM_BREAKPOLARITY_HIGH;
  sBreakDeadTimeConfig.BreakFilter = 0;
  sBreakDeadTimeConfig.AutomaticOutput = TIM_AUTOMATICOUTPUT_DISABLE;
  if (HAL_TIMEx_ConfigBreakDeadTime(&htim16, &sBreakDeadTimeConfig) != HAL_OK)
  {
    Error_Handler();
  }
  HAL_TIM_MspPostInit(&htim16);

}

void HAL_TIM_Base_MspInit(TIM_HandleTypeDef* tim_baseHandle)
{

  if(tim_baseHandle->Instance==TIM1)
  {
    /* TIM1 clock enable */
    __HAL_RCC_TIM1_CLK_ENABLE();

    /* TIM1 interrupt Init */
    HAL_NVIC_SetPriority(TIM1_UP_TIM16_IRQn, 0, 0);
    HAL_NVIC_EnableIRQ(TIM1_UP_TIM16_IRQn);
  }
  else if(tim_baseHandle->Instance==TIM16)
  {
    /* TIM16 clock enable */
    __HAL_RCC_TIM16_CLK_ENABLE();

    /* TIM16 interrupt Init */
    HAL_NVIC_SetPriority(TIM1_UP_TIM16_IRQn, 0, 0);
    HAL_NVIC_EnableIRQ(TIM1_UP_TIM16_IRQn);
  }
}
void HAL_TIM_MspPostInit(TIM_HandleTypeDef* timHandle)
{

  GPIO_InitTypeDef GPIO_InitStruct = {0};
  if(timHandle->Instance==TIM1)
  {
    __HAL_RCC_GPIOA_CLK_ENABLE();
    __HAL_RCC_GPIOB_CLK_ENABLE();
    /**TIM1 GPIO Configuration
    PA7     ------> TIM1_CH1N
    PA8     ------> TIM1_CH1
    PB15     ------> TIM1_CH3N
    PA10     ------> TIM1_CH3
    */
    GPIO_InitStruct.Pin = GPIO_PIN_7|GPIO_PIN_8|GPIO_PIN_10;
    GPIO_InitStruct.Mode = GPIO_MODE_AF_PP;
    GPIO_InitStruct.Pull = GPIO_NOPULL;
    GPIO_InitStruct.Speed = GPIO_SPEED_FREQ_MEDIUM;
    GPIO_InitStruct.Alternate = GPIO_AF1_TIM1;
    HAL_GPIO_Init(GPIOA, &GPIO_InitStruct);

    GPIO_InitStruct.Pin = GPIO_PIN_15;
    GPIO_InitStruct.Mode = GPIO_MODE_AF_PP;
    GPIO_InitStruct.Pull = GPIO_NOPULL;
    GPIO_InitStruct.Speed = GPIO_SPEED_FREQ_MEDIUM;
    GPIO_InitStruct.Alternate = GPIO_AF1_TIM1;
    HAL_GPIO_Init(GPIOB, &GPIO_InitStruct);

  }
  else if(timHandle->Instance==TIM16)
  {
    __HAL_RCC_GPIOB_CLK_ENABLE();
    /**TIM16 GPIO Configuration
    PB6     ------> TIM16_CH1N
    */
    GPIO_InitStruct.Pin = EXCITER_Pin;
    GPIO_InitStruct.Mode = GPIO_MODE_AF_PP;
    GPIO_InitStruct.Pull = GPIO_NOPULL;
    GPIO_InitStruct.Speed = GPIO_SPEED_FREQ_VERY_HIGH;
    GPIO_InitStruct.Alternate = GPIO_AF14_TIM16;
    HAL_GPIO_Init(EXCITER_GPIO_Port, &GPIO_InitStruct);

  }

}
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

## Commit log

2025-06-29 added stuff
    [coil.kicad_sch, touchpad.kicad_pcb, touchpad.kicad_sch]
2025-06-30 finished touchpad
    [touchpad.kicad_pcb, touchpad.kicad_sch]
2025-06-30 started on board
    [board.kicad_pcb, board.kicad_sch]
2025-07-01 started schematics
    [analog.kicad_sch, board.kicad_sch, touchpad.kicad_pcb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]
2025-07-01 update schmatic
    [board.kicad_sch]
2025-07-02 fixed stuff
    [analog.kicad_sch, board.kicad_pcb, board.kicad_sch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]
2025-07-02 added .2mm spacing
    [touchpad.kicad_pcb]
2025-07-03 update footprints
    [analog.kicad_sch, board.kicad_pcb, board.kicad_sch]
2025-07-04 added more stuff
    [analog.kicad_sch, board.kicad_sch]
2025-07-04 fnished shcamtic
    [board.kicad_pcb, board.kicad_sch]
2025-07-05 added touches
    [board.kicad_pcb, board.kicad_sch, touchpad.kicad_pcb]
2025-07-06 pcb power start
    [board.kicad_pcb, board.kicad_sch]
2025-07-13 bunch o f stuff
    [board.kicad_pcb, board.kicad_sch, bom.csv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]
2025-07-13 finished board
    [analog.kicad_sch, board.kicad_pcb, board.kicad_sch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]
2025-07-13 battery adn 3d stuff
2025-07-15 impdance matching
    [board.kicad_pcb, board.kicad_sch, bom.csv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]
2025-07-16 esd prtot
    [board.kicad_pcb, board.kicad_sch]

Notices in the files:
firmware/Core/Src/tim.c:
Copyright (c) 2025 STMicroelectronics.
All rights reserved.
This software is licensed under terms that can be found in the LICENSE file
